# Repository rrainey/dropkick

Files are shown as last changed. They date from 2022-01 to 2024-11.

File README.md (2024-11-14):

# Dropkick
**An experimental logger for skydivers**

These devices are designed to be carried in a skydiver's breast pocket. The device loggs GPS position, barometric altitude, body rotation rates, and acceleration forces.
Data is logged to a SD card for analysis on the ground.

There are two board variants active in this project: V4 SAM, is the board I use for skydiving. V5-CAM is a design repurposed for real-time
use on a telescope pointing experiments. See [CHANGELOG.md](CHANGELOG.md) for a more detailed history.

## Sponsorship
I'd like to thank [PCBWay](https://www.pcbway.com/) for their generous sponsorship. PCBWay supplied prototype PCBs and solder stencils for the CAM variant of this project. My experience with PCBWay predates their sponsorship here. PCBWay has been a great choice for my projects. They deliver good PCBs and accurate stencils quickly.
 
 ## Description

This is a stand-alone, battery-powered data logger designed to be
carried by a skydiver during their jump.  It includes a GNSS (GPS) receiver, 6-DOF IMU, and altitude sensors. Data from all sensors is logged onto a Micro-SD card. The logged data can be reviewed post-jump by to-be-designed software.

One objective of this project is to research compact GNSS receiver performance in the dynamic environment that a skydiver routinely experiences. As such, there are currently two different u-blox receiver modules that I'm testing. There is a distinct PCB for each board variant.

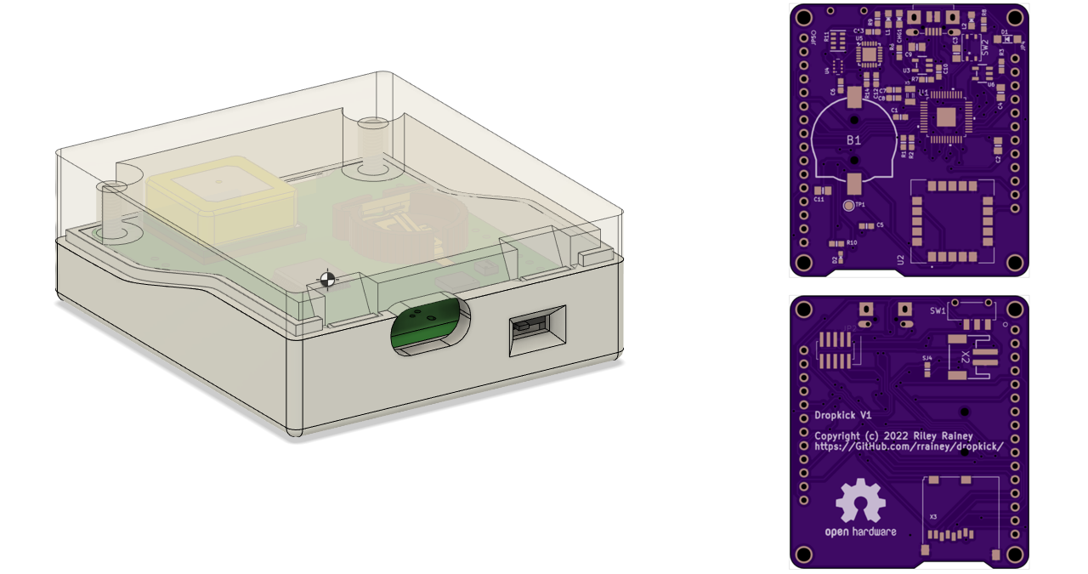
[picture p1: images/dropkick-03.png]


## Directory Structure
* **pcb-sam** - KiCad 6 PCB project files for the [u-blox SAM-M10Q](https://content.u-blox.com/sites/default/files/SAM-M8Q_DataSheet_%28UBX-16012619%29.pdf) variant (this is the preferred variant for skydiving)
* **pcb-cam** - KiCad 7 PCB project files for the [u-blox CAM-M8](https://content.u-blox.com/sites/default/files/CAM-M8-FW3_DataSheet_%28UBX-15031574%29.pdf) variant
* **enclosure** - Fusion 360 enclosure; designed to be 3D-printed
* **firmware** - Arduino-based firmware for the microcontroller
* **images** - supporting images and videos
* **analysis** - GNU Octave-based log file analysis software

Gerber production files generated by KiCad are included in the PCB directories.

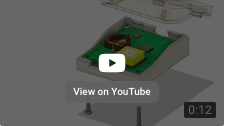
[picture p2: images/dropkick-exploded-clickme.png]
Exploding view (https://youtu.be/SXqk_i92HAI)


Exploded enclosure view (click to view)

## Specifications

Enclosure Dimensions: 58mm x 51mm x 20mm

Power: rechargeable 500mAh Li-Polymer battery

Unit Weight: 55 grams

Storage: removable microSD card

Log file format: [one log file for each jump](LOG-FORMAT.md); raw log format is an extension of NMEA0183.

USB micro-B connector (for recharging and programming)

Bootloader programmed via a 10-pin J-Link compatible connector; routine Arduino programming via the USB connector.

** Compiling Firmware
The Arduino board type should be set to "Adafruit Trinket M0" with Tiny USB enabled.

These libraries are required:
- Adafruit_BMP3XX
- ICM42688
- SparkFun u-blox GNSS Arduino_Library
- MicroNMEA  (2.0.6)
- SD (install the custom fork that I maintain on github)

## PCB Notes
My prototype circuit boards were fabricated by both OSHPark and PCBgogo. Both are excellent manufacturers for hobbyists.

### Bootloader

I flash all variants with the [Adafruit Trinket M0 UF2 bootloader](https://github.com/adafruit/uf2-samdx1/releases/download/v3.15.0/bootloader-trinket_m0-v3.15.0.bin) bin image. The current version is 3.15. Programming is performed via a Segger J-Link USB adapter using Microchip Studio (formerly Atmel Studio). Use Device = "ATSAMD21G18A". Program from the bootload .bin image file and then set the USER_WORD_0.NVMCTRL_BOOTPROT fuse to 8192 bytes.

## Solder Reflow

The solder reflow process has turned out to be a tricky step in constructing the PCBs, particularly with the SAM-M8Q IC.  Basically it requires extra heat soak in
  order to properly flow the solder.  Some u-blox instructions are repeated below, but I'll ultimately add some notes about what worked best for me.

The [u-blox Hardware Integration Manual](https://www.u-blox.com/en/docs/UBX-16018358) provides some detailed requirements for soldering the GNSS module to a PCB:

> ### Soldering paste

>Use of "no clean" soldering paste is highly recommended, as it does not require cleaning after the soldering process has taken place. The paste in the example below meets these criteria.

> * Soldering paste: OM338 SAC405 / Nr.143714 (Cookson Electronics)

> * Alloy specification: Sn 95.5/ Ag 4/ Cu 0.5 (95.5% tin/ 4% silver/ 0.5% copper)

> * Melting temperature: 217 °C

> * Stencil thickness: 120 um

> The final choice of the soldering paste depends on the approved manufacturing procedures. The paste-mask geometry for applying soldering paste should meet the recommendations. 

> ### Reflow soldering

> A convection-type soldering oven is highly recommended over the infrared-type radiation oven. Convection-heated ovens allow precise control of the temperature, and all parts will heat up evenly, regardless of material properties, thickness of components and surface color. As a reference, see the "IPC-7530 Guidelines for temperature profiling for mass soldering (reflow and wave) processes”, published in 2001.

> ### Preheat phase

>During the initial heating of component leads and balls, residual humidity will be dried out. Note that this preheat phase will not replace prior baking procedures.

> * Temperature rise rate: max. 3 °C/s. If the temperature rise is too rapid in the preheat phase it may cause excessive slumping.

> * Time: 60 - 120 s. If the preheat is insufficient, rather large solder balls tend to generate. Conversely, if performed excessively, fine balls and large balls will be generated in clusters.

> * End temperature: 150 - 200 °C. If the temperature is too low, non-melting tends to be caused in areas containing large heat capacity. 

> ### Heating and Reflow Phase

> The temperature rises above the liquidus temperature of 217 °C. Avoid a sudden rise in temperature as the slump of the paste could become worse.

> * Limit time above 217 °C liquidus temperature: 40 - 60s

> * Peak reflow temperature: 245 °C

SAC405 solder paste is relatively expensive. I have been unable to locate SAC405 in hobbyist-friendly quantities, so I opted to use SAC305 for these prototypes. The melting qualities are quite similar, and it retains the essential "no clean" properties required by U-blox -- at the cost of [potentially having slightly less sound solder connections](https://citeseerx.ist.psu.edu/viewdoc/download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,comparable%20to%20that%20of%20SAC405.).

I own a very basic infrared-type reflow oven, a Puhui T962. Even though infrared ovens are not recommended by U-blox, I decided to use it and pay careful attention to the programming of heating profile. First, I did a series to timing experiments with the standard profiles comparing them against the u-blox requirements. It turned out that my oven does not have a standard heating profile that would comply with these requirements. In particular, the closest standard profile held the oven temperature above 217 °C for roughly 90 seconds. That's far longer than the 40 to 60 seconds stated in the requirements. I had to develop a custom profile to match.

I programmed this profile into the reflow oven:
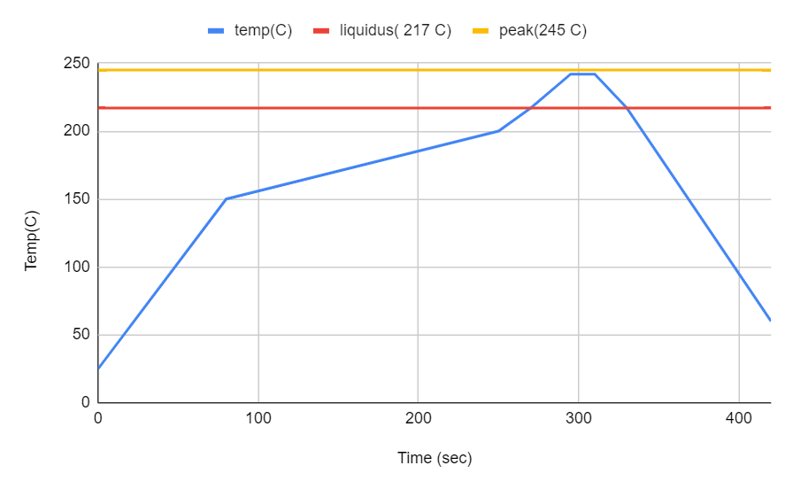
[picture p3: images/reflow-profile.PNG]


## Enclosure Notes
The enclosure is designed to be 3D printed. Tolerances between the upper enclosure, lower enclosure, and the PCB
 are quite tight - printing precision will be important. Since 3D printing technologies will vary in their precision, 
 you may need to scale or otherwise modify the objects to adequately match the final measurements in the original design.

For example, I printed the prototype enclosure on a MakerBot Replicator 2 (PLA) printer.  Using the default print settings
 I know that an object will shrink typically by about 1% post-printing.  I set the scale to 101% to compensate for that 
 in the MakerBot Desktop tooling and the end result works well.

## Credits

This PCB design is based on several Adafruit Feather and Stemma QT sensor boards.  Adafruit maintains a family of
 excellent microcontroller and sensor evaluation boards and companion software.  Support them. They deserve it.

The enclosure for this project was designed using the personal edition of Fusion 360. Autodesk supports the Maker community through access to this epic design tool.  Try it out.

## Disclaimer
THE SOFTWARE IS PROVIDED "AS IS", WITHOUT WARRANTY OF ANY KIND, EXPRESS OR IMPLIED, INCLUDING BUT NOT LIMITED TO THE WARRANTIES OF MERCHANTABILITY,
FITNESS FOR A PARTICULAR PURPOSE AND NONINFRINGEMENT. IN NO EVENT SHALL THE
AUTHORS OR COPYRIGHT HOLDERS BE LIABLE FOR ANY CLAIM, DAMAGES OR OTHER
LIABILITY, WHETHER IN AN ACTION OF CONTRACT, TORT OR OTHERWISE, ARISING FROM,
OUT OF OR IN CONNECTION WITH THE SOFTWARE OR THE USE OR OTHER DEALINGS IN THE
SOFTWARE.

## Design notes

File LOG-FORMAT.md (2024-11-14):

# Log File Format

A Dropkick log is a CSV text file. It is composed of [NMEA 0183](https://en.wikipedia.org/wiki/NMEA_0183) standard GPS records, or "sentences" using NMEA terminology,
 interspersed with the application-specific sentences described below.

 While the dropkick box is turned on, a new log file will be created when the device detects that aircraft carrying the skydiver has taken off.  Logging continues 
 until a short time after the jumper reaches the ground.

 ## Time bases

 Some NMEA sentences include a UTC timestamp computed by the GNSS receiver. A native clock in an Arduino application is the
 millis() system call.  It is a unsigned 32-bit value reflecting the number of milliseconds
 elapsed since boot time.  Both time values
 will appear in a log file.  These two timelines are designed to be correlated using information in a $PTH sentence, described below.

## NMEA Checksums

As of version 55/155, all sentences end with a three character NMEA checksum sequence ("*HH", where HH is the hex representation of the checksum byte).  These  are omitted from the examples shown below for clarity.

## $PVER Record

A single instance of this record appears as the first sentence of each log.  It documents
 the software version used to create the file. The app version is an integer version number; the "hundreds" digit is used to
 designate whether the file originated from a Dropkick(0) or the newer Tempo board(1). This is an imperfect scheme.  It will make for future issues
 with versioning semantics. I'll have to fix that with an updated version of this sentence some time later.

### Comma-separated Fields

 | Description   |                                        |
 |---------------|----------------------------------------|
| $PVER         | Record identifier                      |
| id string | ID of this app version   |
| version number       | an integer version number of the application; a '1' in the decimal hundreds place indicatess it was created by Tempo, not Dropkick        |

### Example 

`$PVER,"Dropkick, version 0.52",52`

## $PIMU Record

### For Dropkick boards

PIMU record logs sensor information from the [MPU6050 IMU IC](https://invensense.tdk.com/wp-content/uploads/2015/02/MPU-6000-Datasheet1.pdf).  The MPU6050 is mounted on the
Dropkick PCB such that the positive X-Axis projects out the SD card slot, the positive Y-Axis projects out the face opposite the USB port, and the positive Z-Axis projects out the "top" of the enclosure.  Since the device might be carried by a skydiver in almost any orientation, it would be up to analysis software to discern the body orientation inferred by actual readings.

### For Tempo boards

The ICM42688-V IMU is installed on Tempo Boards. Values are reported in Case Axes (body axes), shown below.

### Comma-separated Fields

| Description | |
|---|---|
| $PIMU | Record identifier |
| millis() timestamp | Time of sample in milliseconds |
| X-accel | expressed in meters per second squared |
| Y-accel | expressed in meters per second squared |
| Z-accel | expressed in meters per second  squared |
| X-rate | raw X rotation rate; expressed in radians per second |
| Y-rate | raw Y rotation rate; expressed in radians per second |
| Z-rate | raw Z rotation rate; expressed in radians per second |

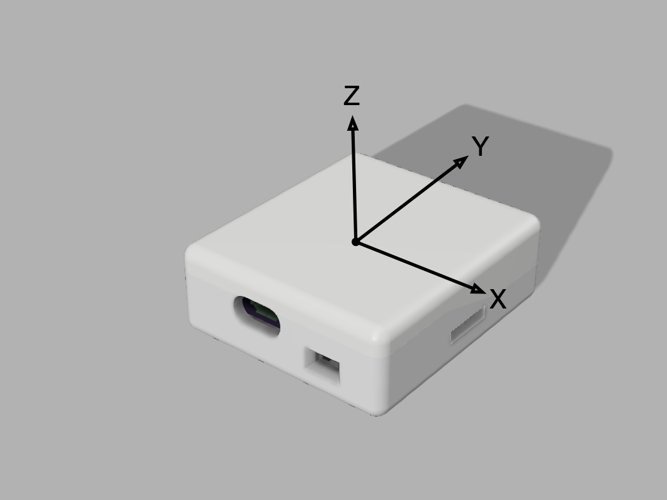
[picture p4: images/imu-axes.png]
Dropkick axes

Dropkick board Body Axes

Tempo Frames
Template board Axes, including the Case (or Body) Axis definitions

## $PIM2 Record (Tempo boards only)

This is the real-time orientation of the jumper expressed as a [Quaternion](https://en.wikipedia.org/wiki/Quaternions_and_spatial_rotation).

The application maintains this orientation quaternion using a 200Hz sample
stream from the IMU. A startup value of [1,0,0,0] is used,
and orientation quaternion is updated to reflect all changes in the body axes from
that original orientation.

This raw orientation quaternion must be transformed into some world frame of reference - North-East-Down, for example - 
in order for it to be useful in analysis of a jump.  I have a few approaches to this in mind, but it remains
as future work in this project.

### Comma-separated Fields

| Description | |
|---|---|
| $PIM2 | Record identifier |
| millis() timestamp | Time of sample in milliseconds |
| W | quaternion w component, non-dimensional |
| X | quaternion x component, non-dimensional |
| Y | quaternion y component, non-dimensional |
| Z | quaternion z component, non-dimensional |

### $PIM2 Example

`$PIM2,13925127,1.0000,0.0000,0.0000,0.0000`

## $PENV Record

This record logs pressure information captured from the 
[DPS310 sensor IC](https://www.infineon.com/dgdl/Infineon-DPS310-DataSheet-v01_02-EN.pdf?fileId=5546d462576f34750157750826c42242) and a resistor ladder used to monitor the VBATT battery line voltage level.

### Comma-separated Fields
| Description | |
|---|---|
| $PENV | Record identifier |
| millis() timestamp | Time of sample in milliseconds |
| static air  pressure | expressed in hPa |
| estimated altitude | based on static air pressure reading for a standard day; expressed in feet |
| VBATT voltage | battery voltage level (3.5V - 3.8V typ.); sampled once every 30 seconds; 
battery voltage isn't reported  on Tempo boards: the value will be set to -1    |

### $PENV Example

`$PENV,13925040,984.62,791.18,3.79`

## $PTH Record

 A PTH record is used to correlate Arduino millis() timestamps with the GNSS computed time of day
  clock information that appears in standard NMEA sentences.  A PTH record will appear immediately 
  following each NMEA GGA or GGL record.  The timestamp present in the record reflects the millis() time at the arrival
  of the first character of the NMEA record.

### $PTH Example

`$PTH,13925296`

## $PSFC Record

This records the estimated surface altitude of the landing area. This value is currently computed directly from the static air pressure assuming a [standard air pressure
lapse rate](https://en.wikipedia.org/wiki/Atmospheric_pressure).

This value can be subtraced from the altitude reports in $PENV sentences to obtain an estimated height above ground level (AGL)

### Comma-separated Fields

| Description | |
|---|---|
| $PSFC | Record identifier |
| estimated surface altitude | Expressed in feet, MSL. Technically speaking, this value reflects the pressure sampled at the device. |

### $PSFC Example

`$PSFC,880`

# $PST Record

This record records application state changes. This internal state machine is used to
identify when to start and stop logging of each jump. 

The application defines WAIT, FLIGHT, JUMPING, and LANDED1 states.  This information might be useful to
isolate specific segments of the jump during post-jump analysis.

### Comma-separated Fields

| Description | |
|---|---|
| $PSFC | Record identifier |
| millis() timestamp | Time of state change in milliseconds |
| New State | WAIT, FLIGHT, JUMPING, or LANDED1  |

### $PST Example

`$PST,1000,FLIGHT`

## Sentence Reporting Rates

Sensor records are written to the file at these rates:

| Sentence Type |  Reporting Rate |
|:---:|:---|
|  PVER | appears as the first line of a log file |
|  PSFC | follows the PVER sentence |
|  GNSS position report | 2 Hz |
|  PIMU | 40 Hz |
|  PIM2 | follows each $PIMU sentence|
|  PENV | 4 Hz |
|  PTH | follows each GGA and VTG record|
|  PST | at each internal state change in the logger |

Valid for version 55/155 and later

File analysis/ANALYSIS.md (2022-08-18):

## General

The main module of this GNU Octave code is Modeler.m.

```bash
$ octave
octave:1>  [t_plot, a_norm_plot, a_filt_plot, ssim] = Modeler.analyze('LOG00014.TXT');
```

The objective is to explore the feasibility to use IMU to accurately estimate the
pose and location of the jumper in freefall and while under canopy.

Pose estimation will require accuracy in both initialization and pose updates.  During initialization, GNSS location fixes and track information can be combined with the apparent gravity vector to keep orientation, position, and velocity information
up to date. Once we detect that the jump has started, we can then transition to using the IMU's roll rate and acceleration sensors to
calculate changes in state.

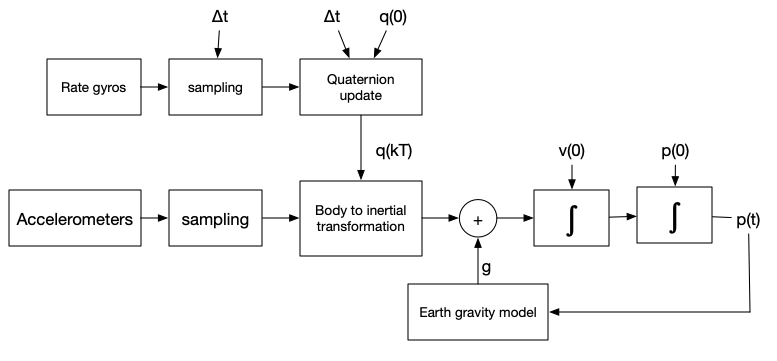
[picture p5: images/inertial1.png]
Basic inertial computations based on IMU sensors


$$
\begin{bmatrix}
\dot{q_0} \\
\dot{q_1} \\
\dot{q_2} \\
\dot{q_3}
\end{bmatrix} = - \frac{1}{2} \begin{bmatrix*}[r] 
 0  &  P  &  Q  &  R \\
-P  &  0  & -R  & Q \\
-Q  &  R  & 0   & -P \\
-R  & -Q  &  P  &  0 \\
\end{bmatrix*}
\begin{bmatrix}
q_0 \\
q_1 \\
q_2 \\
q_3
\end{bmatrix}
$$

From ANSI/AIAA R-004-1992 "Atmospheric and Space Flight Vehicle Coordinate Systems"; Euler body angles can be recovered from an orientation Quaternion in this way:

$$
\begin{split}
\phi & =\arctan[ \frac{ 2( q_2 q_3 + q_0 q_1 ) }{ ( q_0^2 + q_3^2 - q_1^2 - q_2^2 ) } ] \\
\\
\theta & = \arcsin[-2 ( q_1 q_3 - q_0 q_2 )] \\
\\
\psi & =  \arctan[ \frac{2( q_1 q_2 + q_0 q_3 ) }{( q_0^2 + q_1^2 - q_2^2 - q_3^2 ) } ] \\
\\
\end{split}
$$

For orientation quaternion initialization, (estimated) body angles may be used:

$$
\begin{split} 
\\
q_0 & = \cos(\frac{\psi}{2}) \cos(\frac{\theta}{2})  \cos(\frac{\phi}{2 }) + 
      \sin(\frac{\psi}{2}) \sin(\frac{\theta}{2})  \sin(\frac{\phi}{2 }) \\
\\
q_1 & = \cos(\frac{\psi}{2}) \cos(\frac{\theta}{2})  \sin(\frac{\phi}{2 }) -
      \sin(\frac{\psi}{2}) \sin(\frac{\theta}{2})  \cos(\frac{\phi}{2 }) \\
\\
q_2 & = \cos(\frac{\psi}{2}) \sin(\frac{\theta}{2})  \cos(\frac{\phi}{2 }) +
      \sin(\frac{\psi}{2}) \cos(\frac{\theta}{2})  \sin(\frac{\phi}{2 }) \\
\\
q_3 & = - \cos(\frac{\psi}{2}) \sin(\frac{\theta}{2})  \sin(\frac{\phi}{2}) +
      \sin(\frac{\psi}{2}) \cos(\frac{\theta}{2})  \cos(\frac{\phi}{2}) \\
\\
\end{split}
$$

Body axes are AIAA-standard, which is X out-the-nose, Y out-the-right-wing, and Z down.

The AIAA-standard North-East-Down coordinate frame is used to express world cordinates. Origin X and Y coordinates for each log file are arbirarily chosen to be the XY location at the start of the log. If needed, the first reported GNSS position may be used to establish the NED origin (with appropriate Z correction applied to compensate for altitude)

| Variables | |
|:---:|---|
| $P, Q, R$ | Body angular velocity rates (sampled) (rad/sec) |
| $a_{B}$ | Sampled body acceleration (m/sec^2)
| $a, v, p$ | 3D Acceleration (sampled), velocity, and position in NED frame (meters) |
| $q$ | Body orientation quaterion (NED Frame) |
| $\phi, \theta, \psi$ | roll, pitch, yaw body angles (radians) |

The gravity model used during analysis is to be determined.

Adams-Bashforth third-order integration will ultimately be used to integrate NED velocity and position.

$$x_{n+1} = x_{n} + \frac{T}{12} ( 5 \dot{x}_{n+1} + 8 \dot{x}_n - \dot{x}_{n-1} ) $$

Where $T$ is the time step.

Euler integration is used for the first two time steps to prime the ABM integrator.

NOTE: In the current version of the code, Euler integration is used throughout.

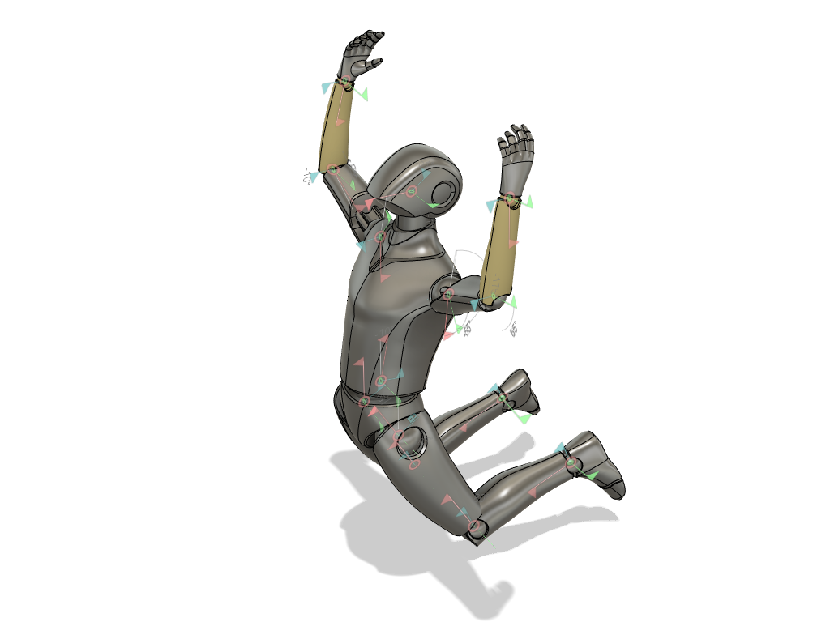
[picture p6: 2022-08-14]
images/jumper-01.png

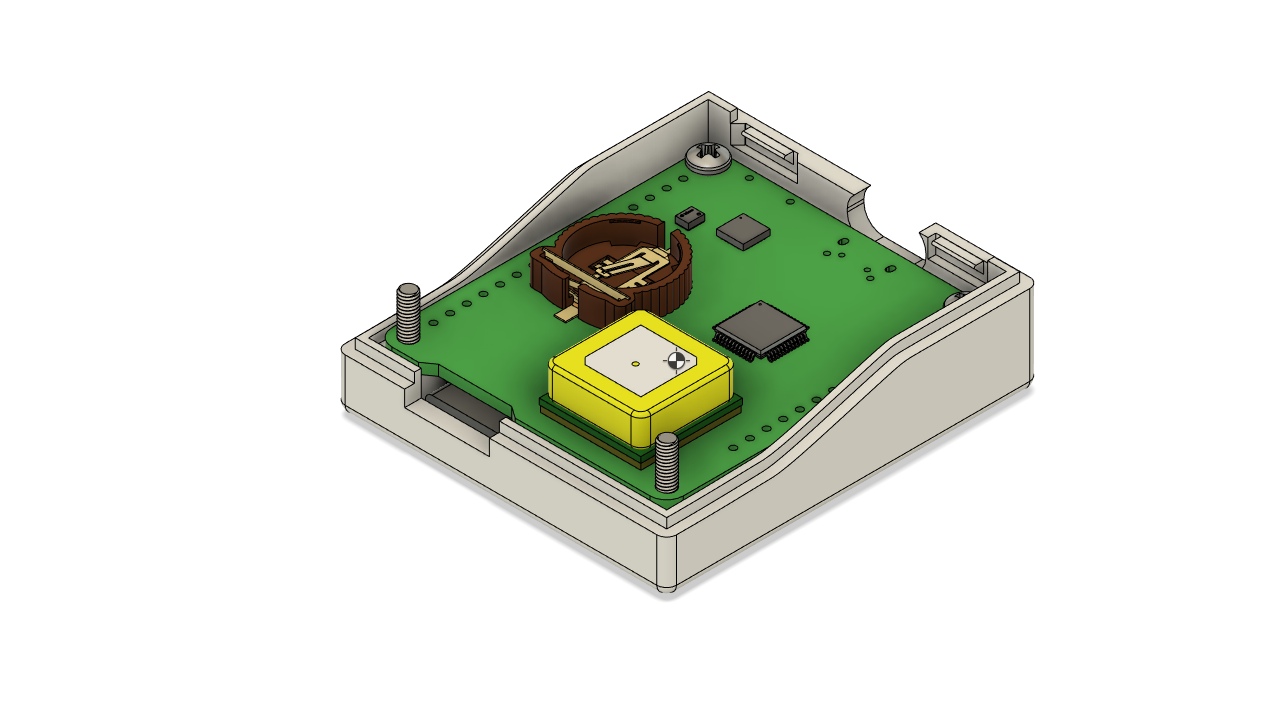
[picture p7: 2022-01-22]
images/dropkick-01.png

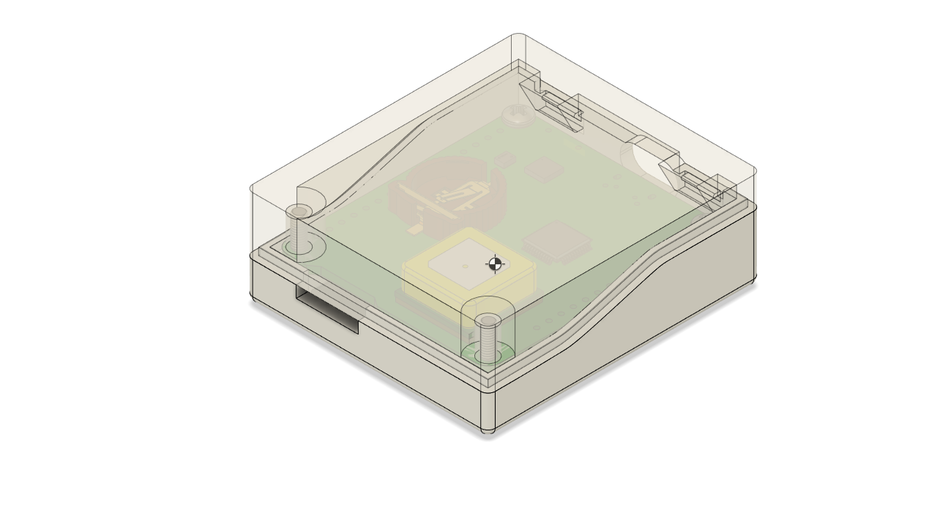
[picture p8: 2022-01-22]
images/dropkick-02.png

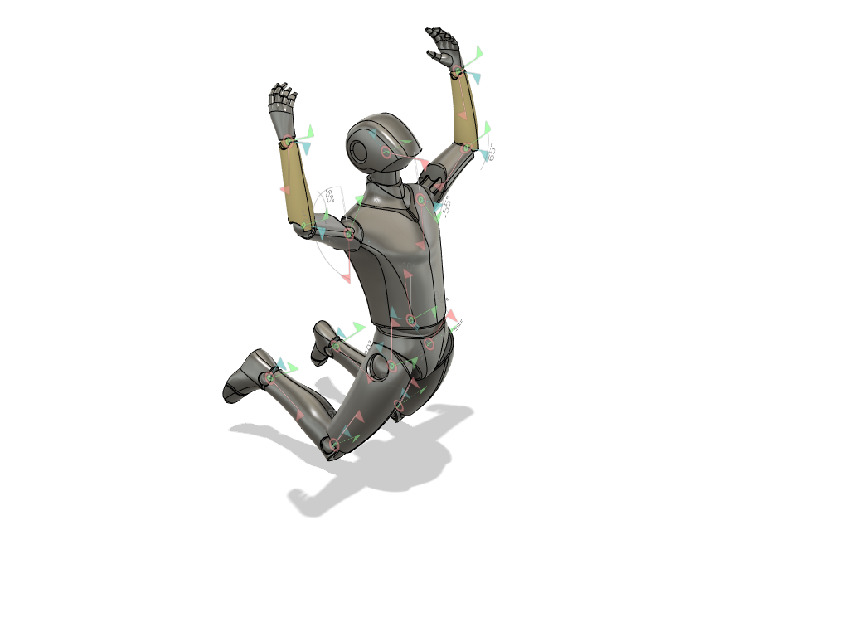
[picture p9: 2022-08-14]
images/jumper-02.png

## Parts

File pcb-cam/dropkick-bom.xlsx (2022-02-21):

Reference | Quantity | Value | Footprint
B1 | 1 | CR1220 | CR1220-2
C1 C5 C10 | 3 | 1uF | Capacitor_SMD:C_0603_1608Metric
C13 | 1 | 2.2nF | Capacitor_SMD:C_0603_1608Metric
C2 C11 | 2 | 10uF | Capacitor_SMD:C_0805_2012Metric
C3 C4 C9 | 3 | 10µF | Capacitor_SMD:C_0805_2012Metric
C6 C12 | 2 | 0.1uF | Capacitor_SMD:C_0603_1608Metric
C7 C8 | 2 | 22pF | Capacitor_SMD:C_0603_1608Metric
CHG1 | 1 | ORANGE | CHIPLED_0805_NOOUTLINE
D1 | 1 | MBR120 | SOD-123
D2 | 1 | GREEN | CHIPLED_0603_NOOUTLINE
H1 H2 H3 H4 | 4 | MountingHole | logger:MOUNTINGHOLE_2.5_PLATED
J1 | 1 | Conn_01x08 | Connector_PinHeader_2.54mm:PinHeader_1x08_P2.54mm_Vertical
JP2 | 1 | 3221-10-0300-00-TR | lib_fp:3221-10-0300-00-TR
L1 | 1 | GREEN | CHIPLED_0805_NOOUTLINE
L2 | 1 | RED | CHIPLED_0805_NOOUTLINE
R1 R2 R3 | 3 | 100K | Resistor_SMD:R_0603_1608Metric
R4 R5 | 2 | 0K | Resistor_SMD:R_0603_1608Metric
R6 R10 R11 R12 R14 | 5 | 10K | Resistor_SMD:R_0603_1608Metric
R7 R9 | 2 | 1K | Resistor_SMD:R_0603_1608Metric
R8 | 1 | 2.2K | Resistor_SMD:R_0603_1608Metric
SJ4 | 1 | SOLDERJUMPER | Resistor_SMD:R_0603_1608Metric
SW1 | 1 | 450405020524 | logger:450405020524
SW2 | 1 | KMR211NG_LFS | logger:KMR211NG LFS
TP1 | 1 | TESTPOINTROUND1.5MM | TESTPOINT_ROUND_1.5MM
U1 | 1 | ATSAMD21G18A-AUT | logger:ATSAMD21G15B-AU
U2 | 1 | CAM-M8C-0 | lib_fr:CAM-M8C-0
U3 | 1 | MCP73831T-2ACI/OT | SOT23-5
U4 | 1 | DPS310XTSA1 | logger:DPS310XTSA1
U5 | 1 | MPU-6050 | QFN24_4MM_SMSC
U6 | 1 | SPX3819-3.3 | SOT23-5
X1 | 1 | microUSB | 4UCONN_20329_V2
X2 | 1 | JSTPH | JSTPH2
X3 | 1 | microsd | MICROSD
X4 | 1 | ANTENNA_U.FL | lib_fr:U.FL
X5 | 1 | 32768Hz | XTAL3215

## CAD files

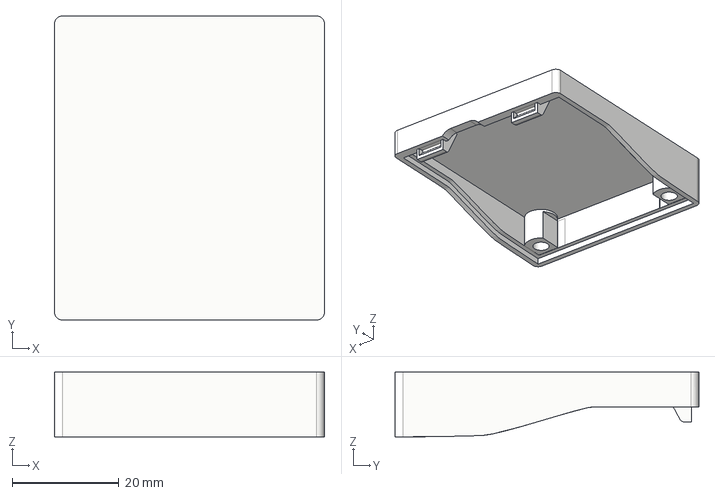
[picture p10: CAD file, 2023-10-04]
enclosure/Upper.step
50.5 x 56.9 x 12.1 mm

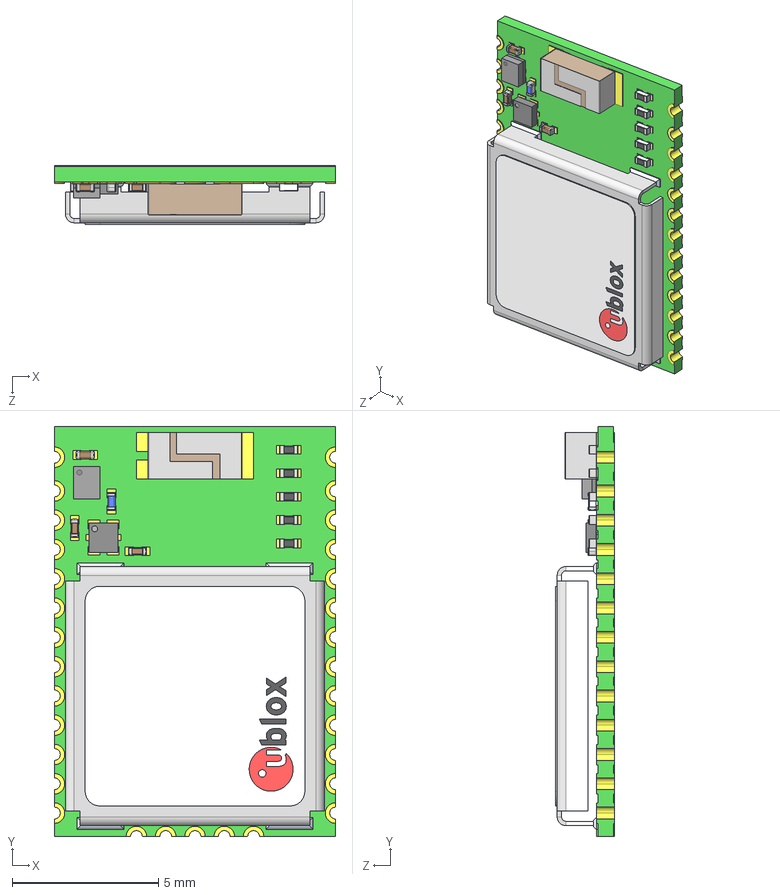
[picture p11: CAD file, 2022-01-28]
pcb-cam/models/CAM.STEP
9.60 x 14.0 x 2.00 mm
SAW_FILTER
C0201 x 3
L0201
NJG1143UA2
SHIELDING_COVER_FOR_CAM_Default
R0201 x 5
CAM_PCB
GPS_CHIP_ANT
u-blox_MAX_label_Default

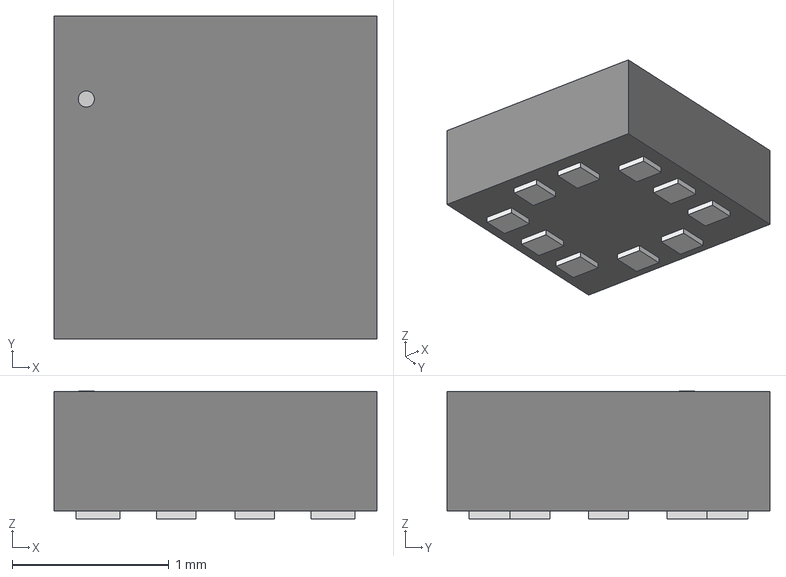
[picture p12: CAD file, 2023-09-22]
pcb-sam/models/LGA10_BMP390_BOS.step
2.06 x 2.06 x 0.815 mm

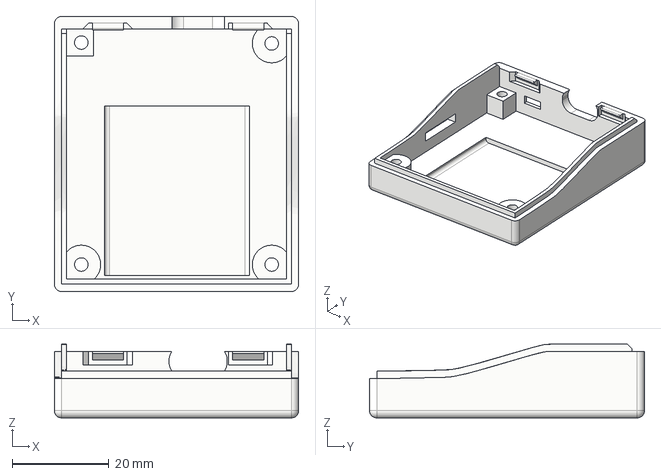
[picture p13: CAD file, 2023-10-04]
enclosure/Lower.step
50.5 x 56.9 x 15.3 mm

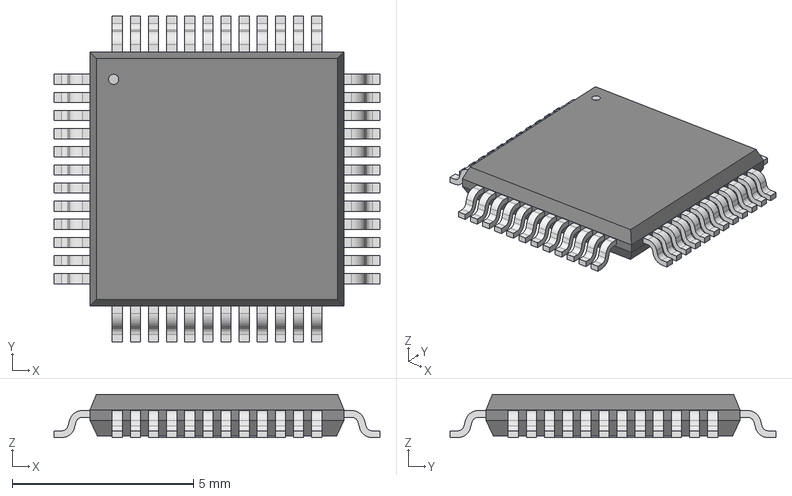
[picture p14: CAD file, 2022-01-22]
pcb-cam/models/TQFP48_7x7MC_MCH.step
8.99 x 8.99 x 1.20 mm

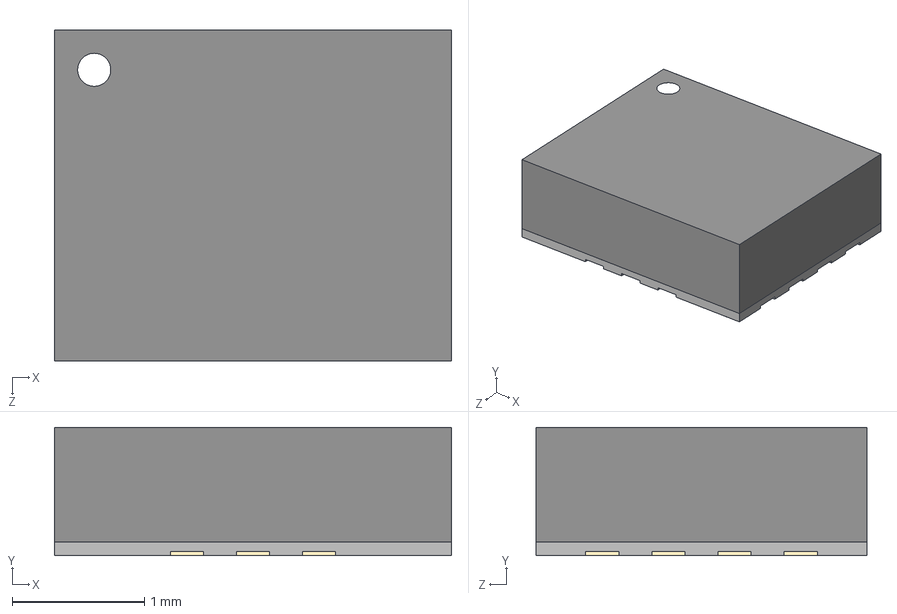
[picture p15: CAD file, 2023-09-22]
pcb-sam/models/ICM-42688-P.step
3.00 x 0.97 x 2.50 mm

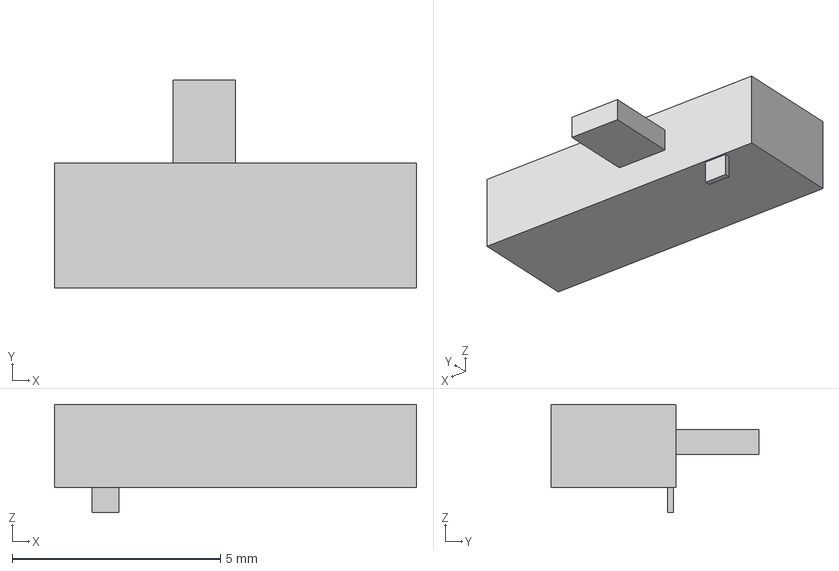
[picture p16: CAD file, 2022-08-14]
enclosure/switch.step
8.70 x 5.00 x 2.60 mm

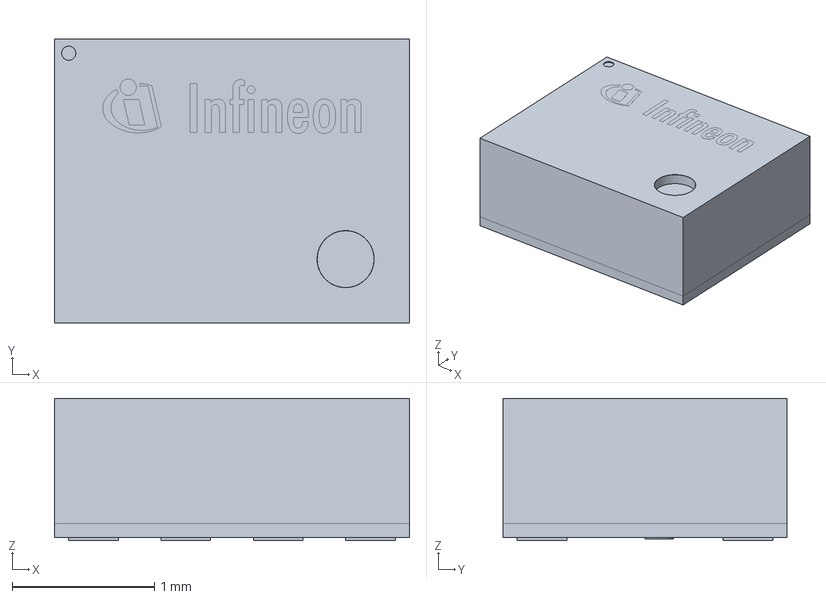
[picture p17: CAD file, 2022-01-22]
pcb-cam/models/DPS310XTSA1.stp
2.50 x 2.00 x 1.00 mm
CADSOFTTOOLS 2.1
CADSOFTTOOLS 2.2
CADSOFTTOOLS 2.3
CADSOFTTOOLS 2.4
CADSOFTTOOLS 2.5
CADSOFTTOOLS 2.6
CADSOFTTOOLS 2.7
CADSOFTTOOLS 2.8
CADSOFTTOOLS 2.9
CADSOFTTOOLS 2.10
CADSOFTTOOLS 2.11
CADSOFTTOOLS 2.12
CADSOFTTOOLS 2.13
CADSOFTTOOLS 2.14
CADSOFTTOOLS 2.15
CADSOFTTOOLS 2.16
CADSOFTTOOLS 2.17
CADSOFTTOOLS 2.18
CADSOFTTOOLS 2.19
CADSOFTTOOLS 2.20
CADSOFTTOOLS 2.21
CADSOFTTOOLS 2.22
CADSOFTTOOLS 2.23
CADSOFTTOOLS 2.24
CADSOFTTOOLS 2.25
CADSOFTTOOLS 2.26
CADSOFTTOOLS 2.27
CADSOFTTOOLS 2.28
CADSOFTTOOLS 2.29
CADSOFTTOOLS 2.30
CADSOFTTOOLS 2.31
CADSOFTTOOLS 2.32
CADSOFTTOOLS 2.33
CADSOFTTOOLS 2.34
CADSOFTTOOLS 2.35
CADSOFTTOOLS 2.36
CADSOFTTOOLS 2.37
CADSOFTTOOLS 2.38
CADSOFTTOOLS 2.39
CADSOFTTOOLS 2.40
CADSOFTTOOLS 2.41
CADSOFTTOOLS 2.42
CADSOFTTOOLS 2.43
CADSOFTTOOLS 2.44
CADSOFTTOOLS 2.45
CADSOFTTOOLS 2.46
CADSOFTTOOLS 2.47
CADSOFTTOOLS 2.48
CADSOFTTOOLS 2.49
CADSOFTTOOLS 2.50
CADSOFTTOOLS 2.51
CADSOFTTOOLS 2.52
CADSOFTTOOLS 2.53
CADSOFTTOOLS 2.54
CADSOFTTOOLS 2.55
CADSOFTTOOLS 2.56
CADSOFTTOOLS 2.57
CADSOFTTOOLS 2.58
CADSOFTTOOLS 2.59
CADSOFTTOOLS 2.60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

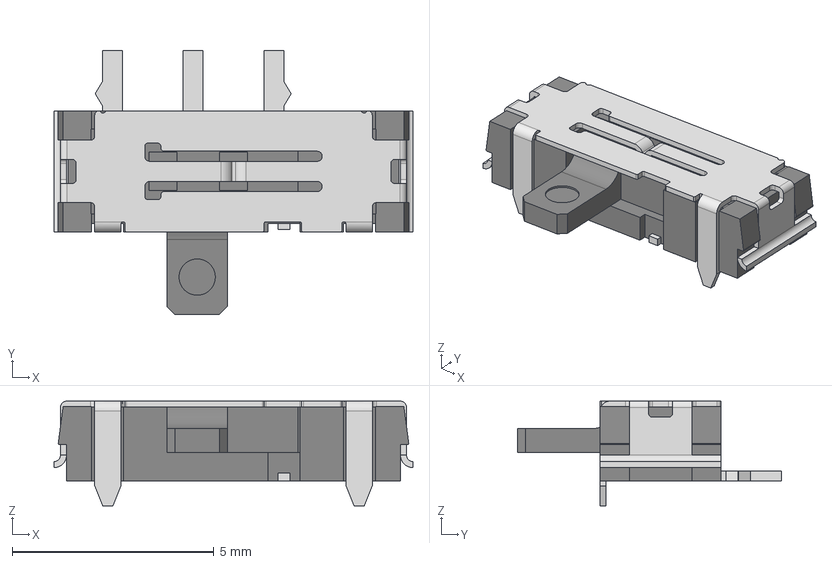
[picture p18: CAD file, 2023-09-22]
pcb-sam/models/STP_450405020524 (rev1).stp
8.90 x 6.55 x 2.60 mm
Frame
Cover
Pin 2
Pin 4
Slider 1
Pin 1
Pin 3
Slider
Pin 5

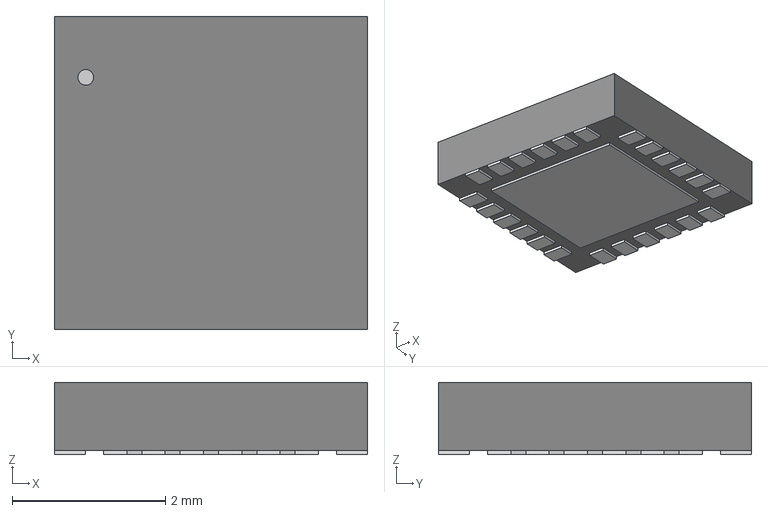
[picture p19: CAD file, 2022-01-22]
pcb-cam/models/QFN24_4X4X0P9_IVS.step
4.09 x 4.09 x 0.942 mm

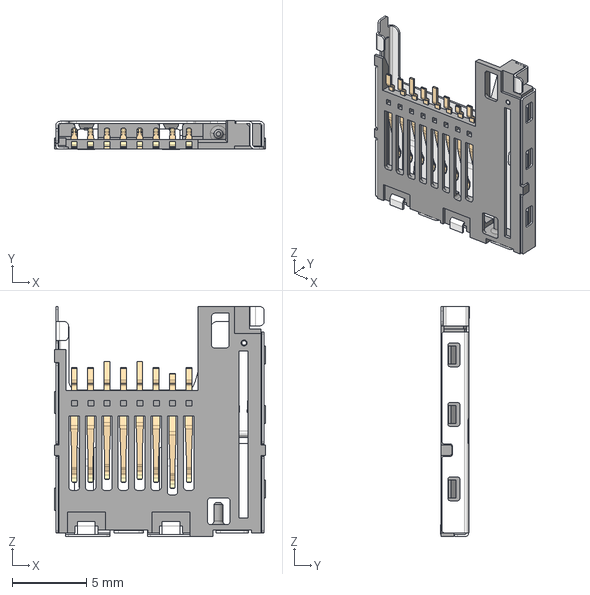
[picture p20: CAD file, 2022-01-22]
pcb-cam/models/MEM2061-01-188-00-A.stp
14.2 x 1.95 x 15.5 mm
ÇÐ³ý-ÀÉì2[2]
ÇÐ³ý-ÀÉì-±¡±Ú2

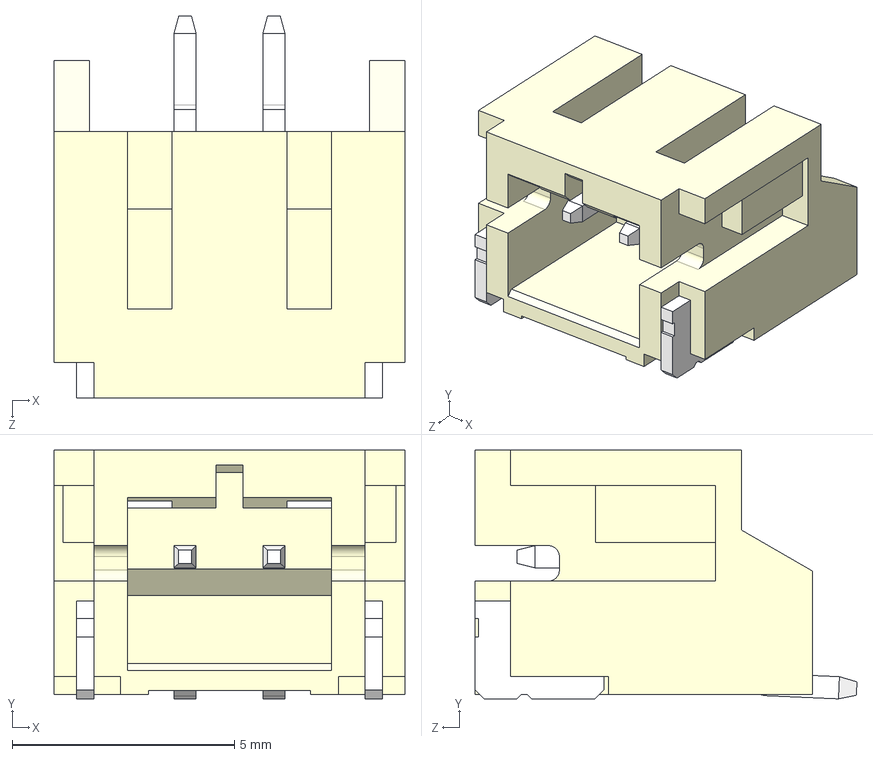
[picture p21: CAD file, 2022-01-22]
pcb-cam/models/S2B-PH-SM4-TB(LF)(SN)--3DModel-STEP-56544.STEP
7.90 x 5.60 x 8.60 mm

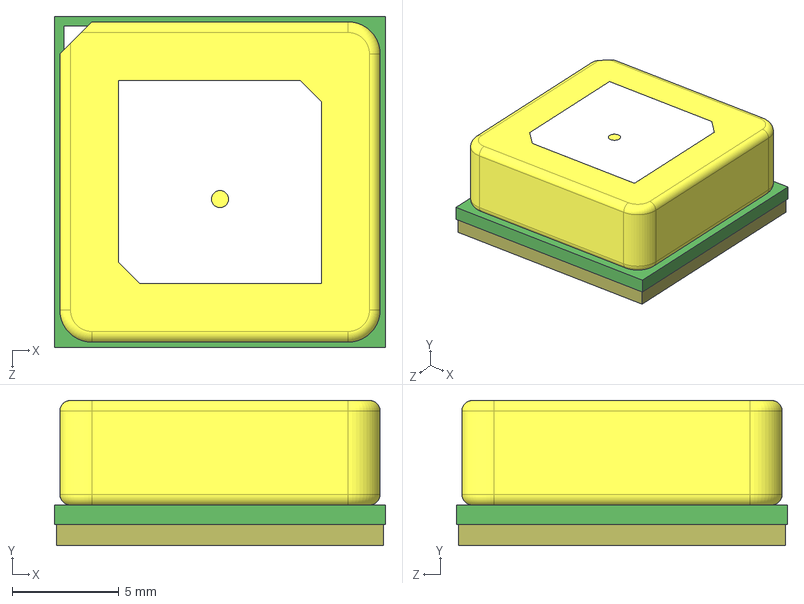
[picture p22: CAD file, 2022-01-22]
pcb-sam/models/SAM-M8Q-0-10.step
15.5 x 6.80 x 15.5 mm

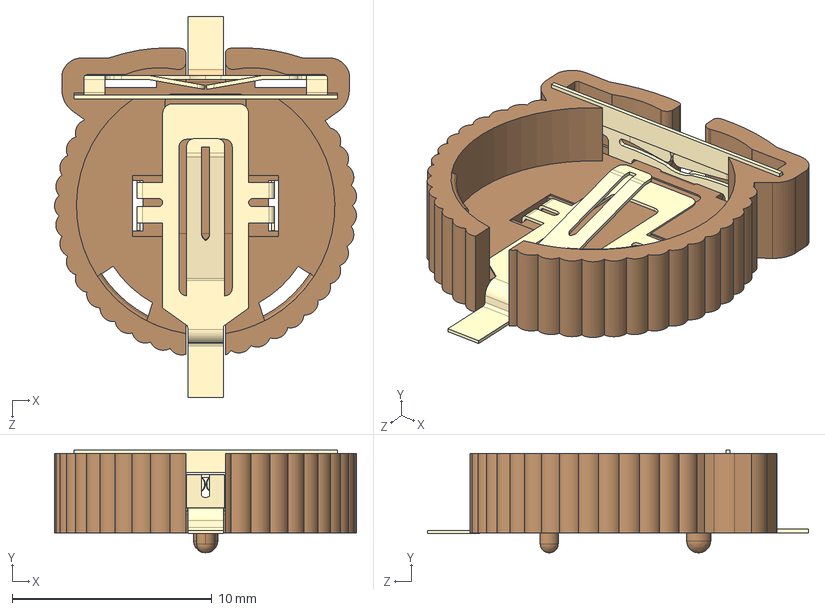
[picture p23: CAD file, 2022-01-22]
pcb-cam/models/keystone-PN1056TR.STEP
15.1 x 5.16 x 19.1 mm

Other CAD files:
enclosure/dropkick.f3z
pcb-cam/models/10103594.stp
pcb-cam/models/20021521-00010XXLFc.stp
pcb-sam/models/10103594.stp
pcb-sam/models/20021521-00010XXLFc.stp

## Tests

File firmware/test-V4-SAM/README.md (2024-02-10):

# TEST-V4-SAM

## A, Arduino sketch designed to strees test the Dropkick SAM V4 board.
This sketch is designed for checkout and stress testing of the
Dropkick SAM V4 board.  This revised board design switched to newer GNSS, IMU, and barometric pressure sensors, so this sketh will not work with earlier variants.

Arduino board configuration settings:

```json
{
    "configuration": "opt=fastest,usbstack=arduino,debug=off",
    "board": "adafruit:samd:adafruit_trinket_m0",
    "sketch": "test-V4-SAM.ino",
    "port": "COM14"
}
```

Your USB port assignment will vary, of course.

## Notes and conclusions
The Dropkick board uses I2C to communicate with all sensors. The newer "peakick" board project does the same.  Both boards exhibit intermittent issues when trying to interact
with sensors at higher sampling rates, probably due to intermittent I2C bus issues.  I did spend some time tuning the I2C bus configuration of both boards, mostly by optimizing the pull-up resistor values.  After tuning, the reliability improved, but intermittent issues persist. Based on that, I have decided that the completely new Tempo board design will use an SPI rather than I2C for the ICM42688 IMU (see https://github.com/rrainey/tempo).

## Credits
This sketch use a custom ICM42688 library.  This IMU driver code is based upon code published by Kris Winer, copyrighted by Tlera Corporation.  I added extensions to add support for the ICM42688 FIFO, interrupts, and allow for better error reporting.  The original code was marked as 
"Library may be used freely and without limit with attribution".  Thank you, Kris and Tlera.  (see https://github.com/kriswiner/ICM42688)

This sketch also includes BMP3-series driver reference code from Bosch Sensortec GmbH. See [BMP3-LICENSE](./BMP3-LICENSE) and https://github.com/boschsensortec/BMP3-Sensor-API for more information.

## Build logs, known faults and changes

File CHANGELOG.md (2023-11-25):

# Dropkick CHANGELOG

## 2023-10-15 CAM V5 Assembly
- assembled and tested first v5-cam board - defective CAM receiver part

## 2023-10-01 CAM V5 Board
- Use internal antenna for the CAM-M8C GNSS Module
- revise CAM-M8C layout to get a cleaner ground plane
- add 30 ohm resistors on CAM-M8C I2C lines to reduce noise
- revise MPU-6050 PCB layout to more closely match the datasheet
- add header lines for SWD programming, switch to 2.0 mm spacing on header

## 2023-09-10 SAM V4 PCB Board
I decided to revise the SAM variant PCB to use more modern ICs:

- Change GNSS to the u-blox SAM-M10Q (the M10Q is pin compatible with the M8Q)
- Change IMU to TDK InvenSense ICM-42688
- Add hardware interrupt lines from the IMU
- Change barometric sensor to the Bosch BMP-390
- Switch to a USB-C connector

## 2022-09-03
I have resolved the buffering issue in the GNSS reporting stream and continue to work on developing analysis tools using Octave.

## 2022-08-18
I have collected the first log files from several jumps. GPS data is usable, although there are intermittent u-blox buffering errors
 interspersed in these logs. I have been exploring the feasibility of pose reconstruction from IMU log data.
 I am using GNU Octave for this investigation. The code resides in the ./analysis subdirectory.  It should be considered entirely experimental
 at this stage - don't trust the accuracy of any of that code based on where I am today.

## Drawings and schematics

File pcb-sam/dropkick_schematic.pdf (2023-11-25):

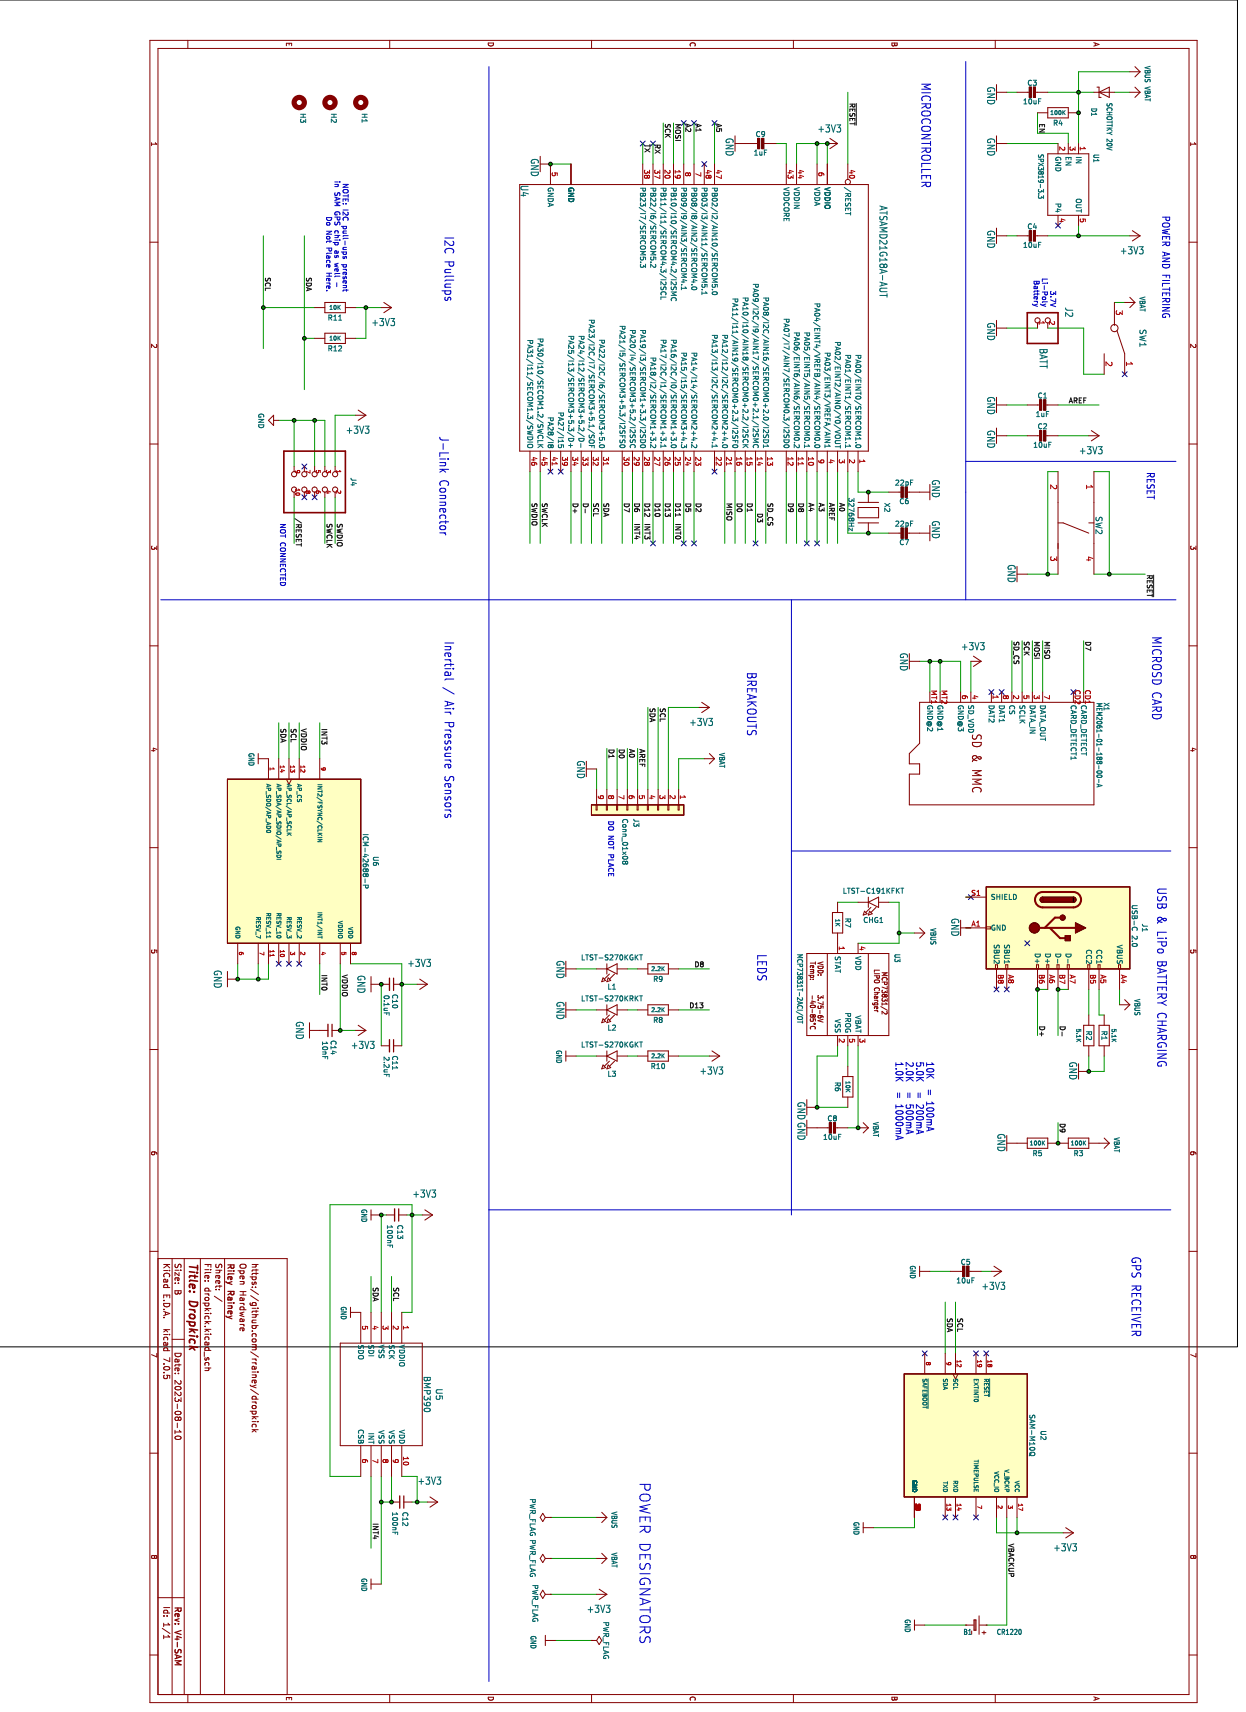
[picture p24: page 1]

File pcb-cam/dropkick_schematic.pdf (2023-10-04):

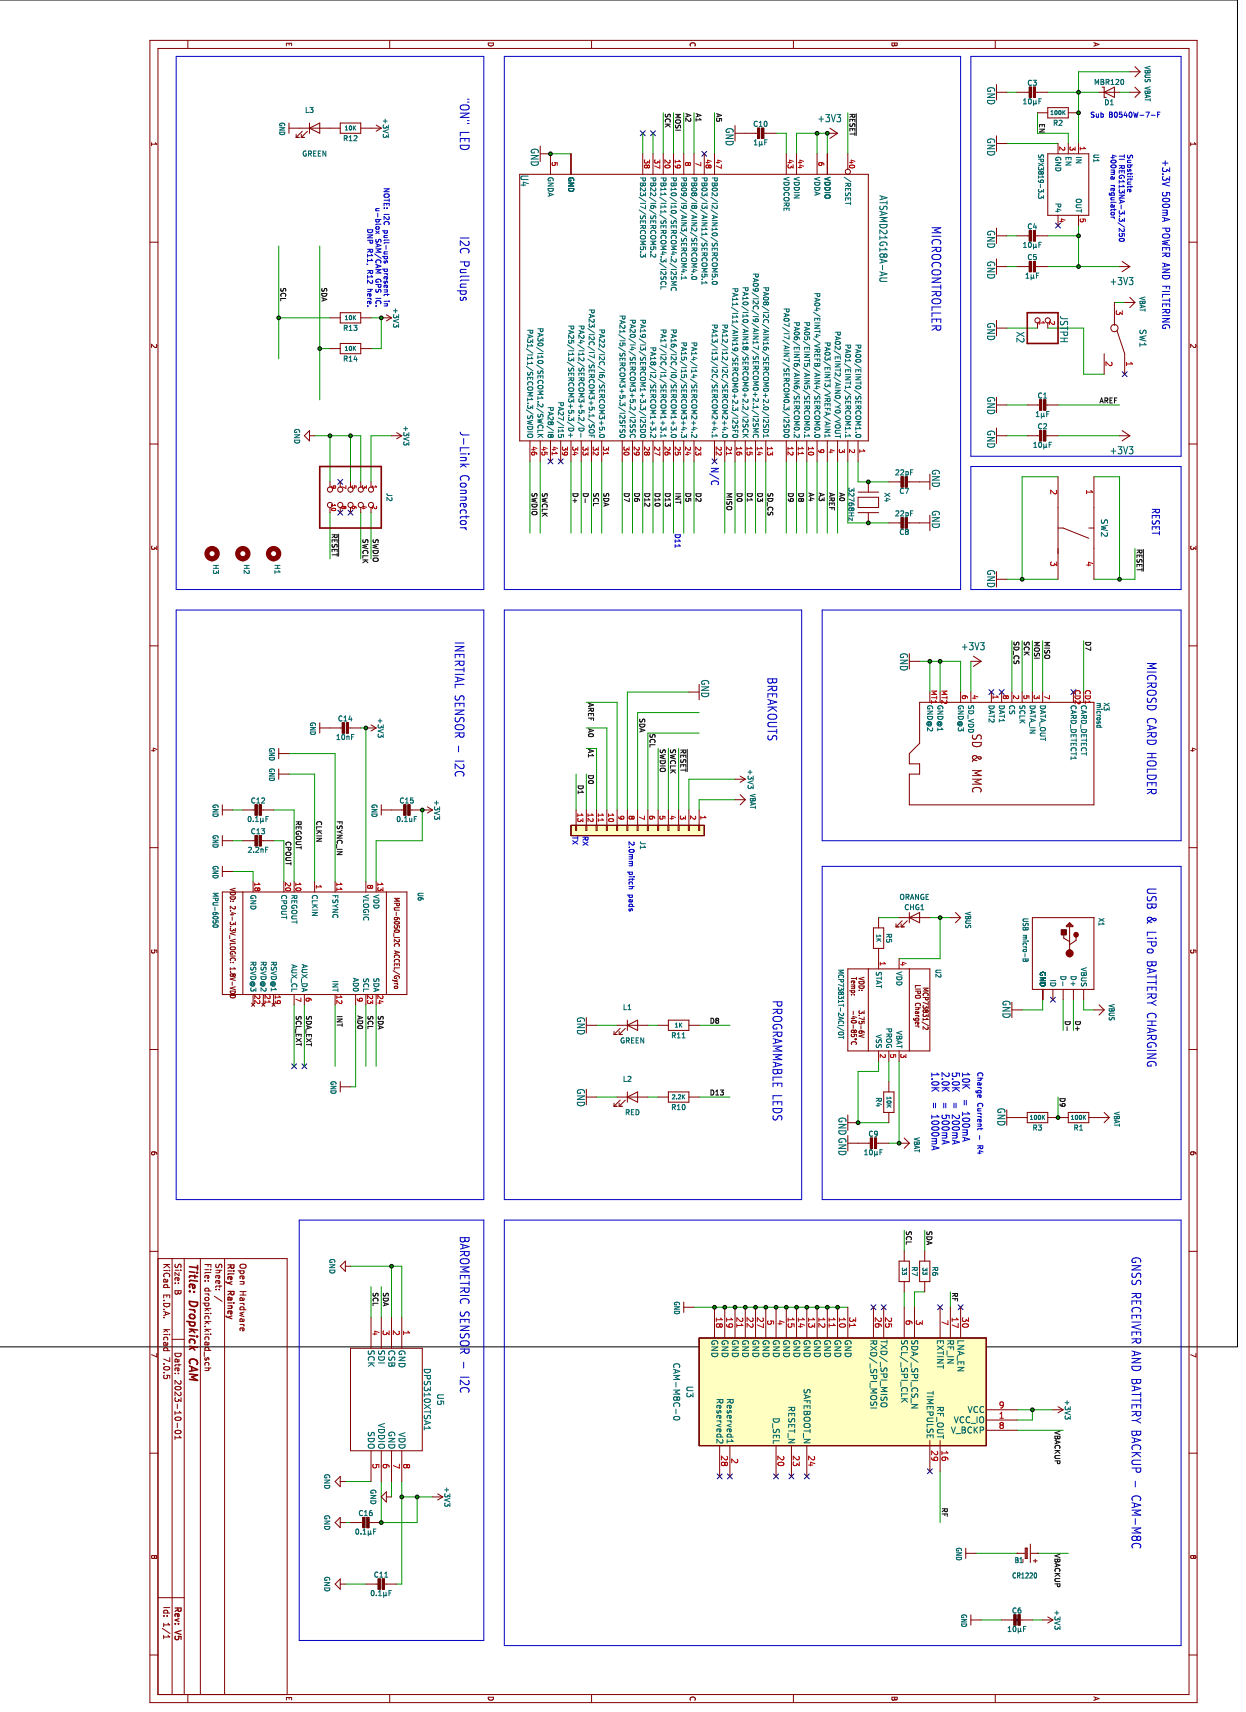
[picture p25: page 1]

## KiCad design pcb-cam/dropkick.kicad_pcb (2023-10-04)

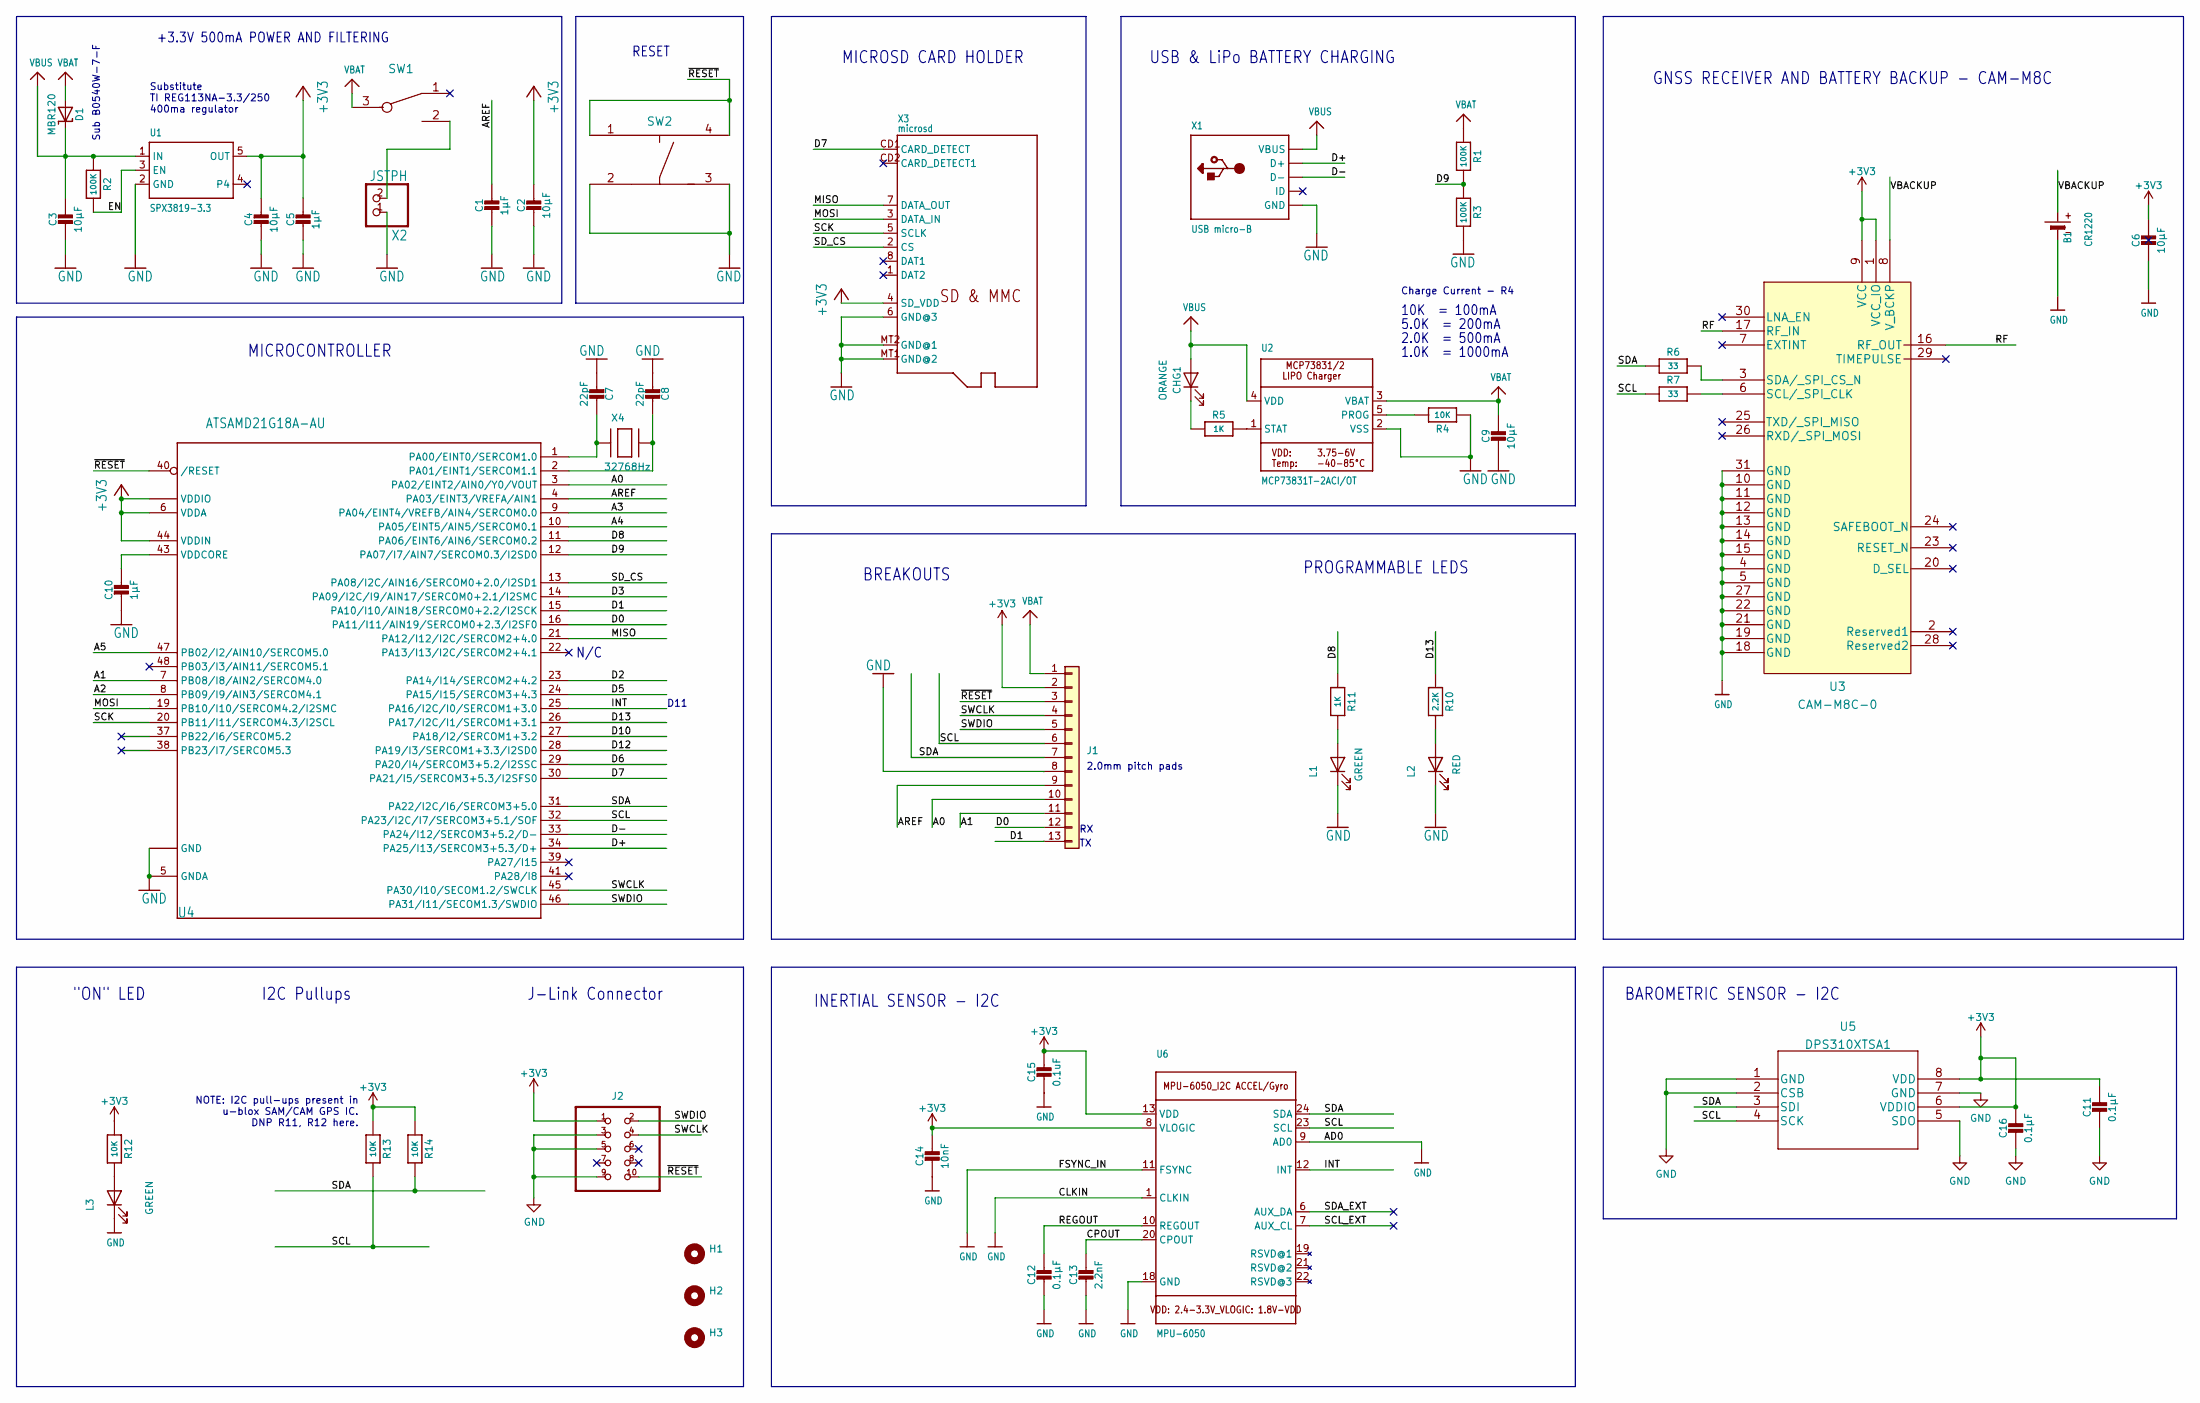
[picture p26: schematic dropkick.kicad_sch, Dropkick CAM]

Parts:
B1: CR1220; CR1220-2; Manufacturer Part 1056TR
C1, C5, C10: 1µF; C_0603_1608Metric
C2, C3, C4, C6, C9: 10µF; C_0805_2012Metric; Manufacturer Part C0805C106K8RACTU
C7, C8: 22pF; C_0603_1608Metric; Manufacturer Part 06035U220FAT2A
C11, C12, C16: 0.1µF; C_0603_1608Metric; Manufacturer Part VJ0603Y104JXXAC
C13: 2.2nF; C_0603_1608Metric; Manufacturer Part C0603C222K1HACAUTO
C14: 10nF; C_0603_1608Metric; Manufacturer Part C0603C222K1HACAUTO
C15: 0.1uF; C_0603_1608Metric; Manufacturer Part C0603C222K1HACAUTO
CHG1: ORANGE; LED_0603_1608Metric; Manufacturer Part AA1112H-TR
D1: MBR120; SOD-123; Manufacturer Part PMEG2005EGWX
H1, H2, H3: MountingHole; MOUNTINGHOLE_2.5_PLATED
J1: Conn_01x13; PinSocket_1x13_P2.00mm_Vertical
J2: 3221-10-0300-00-TR; Manufacturer Part 3221-10-0300-00-TR
L1, L3: GREEN; LED_0603_1608Metric; Manufacturer Part LTST-S270KGKT
L2: RED; LED_0603_1608Metric; Manufacturer Part LTST-S270KRKT
R1, R2, R3: 100K; R_0603_1608Metric; Manufacturer Part TNPW0603100KBEEA
R4, R12, R13, R14: 10K; R_0603_1608Metric
R5, R11: 1K; R_0603_1608Metric
R6, R7: 33; R_0402_1005Metric
R10: 2.2K; R_0603_1608Metric; Manufacturer Part CRCW06032K20FKEAHP
SW1: 450405020524; Manufacturer Part 450405020524
SW2: KMR211NG_LFS; KMR211NG LFS; Manufacturer Part KMR211NG LFS
U1: SPX3819-3.3; SOT23-5; Manufacturer Part SPX3819M5-L-3-3/TR
U2: MCP73831T-2ACI/OT; SOT23-5; Manufacturer Part MCP73831T-2ACI/OT
U3: CAM-M8C-0; Manufacturer Part CAM-M8C-0
U4: ATSAMD21G18A-AU; ATSAMD21G15B-AU; Manufacturer Part ATSAMD21G18A-AU
U5: DPS310XTSA1; Manufacturer Part DPS310XTSA1
U6: MPU-6050; MPU6XXX_QFN24_4MM_SMSC; Manufacturer Part MPU-6050
X1: USB micro-B; 4UCONN_20329_V2; Manufacturer Part 4UCONN_20329_V2
X2: JSTPH; JSTPH2; Manufacturer Part S2B-PH-SM4-TB
X3: microsd; MICROSD; Manufacturer Part MEM2061-01-188-00-A
X4: 32768Hz; XTAL3215; Manufacturer Part FC-135 32.7680KA-A5

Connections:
+3V3: C2.1, C4.1, C5.1, C6.1, C11.1, C14.1, C15.1, C16.1, J1.2, J2.1, R12.1, R13.1, R14.1, U1.5 (OUT), U3.1 (VCC_IO), U3.9 (VCC), U4.6 (VDDA), U4.17 (VDDIO), U4.36 (VDDIO), U4.44 (VDDIN), U5.6 (VDDIO), U5.8 (VDD), U6.8 (VLOGIC), U6.13 (VDD), X3.4 (SD_VDD)
/A0: J1.10, U4.3 (PA02/EINT2/AIN0/Y0/VOUT)
/A1: J1.11, U4.7 (PB08/I8/AIN2/SERCOM4.0)
/A2: U4.8 (PB09/I9/AIN3/SERCOM4.1)
/A3: U4.9 (PA04/EINT4/VREFB/AIN4/SERCOM0.0)
/A4: U4.10 (PA05/EINT5/AIN5/SERCOM0.1)
/A5: U4.47 (PB02/I2/AIN10/SERCOM5.0)
/AREF: C1.1, J1.9, U4.4 (PA03/EINT3/VREFA/AIN1)
/CPOUT: C13.1, U6.20 (CPOUT)
/D0: J1.12, U4.16 (PA11/I11/AIN19/SERCOM0+2.3/I2SF0)
/D1: J1.13, U4.15 (PA10/I10/AIN18/SERCOM0+2.2/I2SCK)
/D2: U4.23 (PA14/I14/SERCOM2+4.2)
/D3: U4.14 (PA09/I2C/I9/AIN17/SERCOM0+2.1/I2SMC)
/D5: U4.24 (PA15/I15/SERCOM3+4.3)
/D6: U4.29 (PA20/I4/SERCOM3+5.2/I2SSC)
/D7: U4.30 (PA21/I5/SERCOM3+5.3/I2SFS0), X3.CD1 (CARD_DETECT)
/D8: R11.1, U4.11 (PA06/EINT6/AIN6/SERCOM0.2)
/D9: R1.2, R3.1, U4.12 (PA07/I7/AIN7/SERCOM0.3/I2SD0)
/D10: U4.27 (PA18/I2/SERCOM1+3.2)
/D12: U4.28 (PA19/I3/SERCOM1+3.3/I2SD0)
/D13: R10.1, U4.26 (PA17/I2C/I1/SERCOM1+3.1)
/D+: U4.34 (PA25/I13/SERCOM3+5.3/D+), X1.D+
/D-: U4.33 (PA24/I12/SERCOM3+5.2/D-), X1.D-
/EN: R2.2, U1.3 (EN)
/INT: U4.25 (PA16/I2C/I0/SERCOM1+3.0), U6.12 (INT)
/MISO: U4.21 (PA12/I12/I2C/SERCOM2+4.0), X3.7 (DATA_OUT)
/MOSI: U4.19 (PB10/I10/SERCOM4.2/I2SMC), X3.3 (DATA_IN)
/REGOUT: C12.1, U6.10 (REGOUT)
/RF: U3.16 (RF_OUT), U3.17 (RF_IN)
/SCK: U4.20 (PB11/I11/SERCOM4.3/I2SCL), X3.5 (SCLK)
/SCL: J1.6, R7.1, R13.2, U4.32 (PA23/I2C/I7/SERCOM3+5.1/SOF), U5.4 (SCK), U6.23 (SCL)
/SCL_EXT: U6.7 (AUX_CL)
/SDA: J1.7, R6.1, R14.2, U4.31 (PA22/I2C/I6/SERCOM3+5.0), U5.3 (SDI), U6.24 (SDA)
/SDA_EXT: U6.6 (AUX_DA)
/SD_CS: U4.13 (PA08/I2C/AIN16/SERCOM0+2.0/I2SD1), X3.2 (CS)
/SWCLK: J1.4, J2.4, U4.45 (PA30/I10/SECOM1.2/SWCLK)
/SWDIO: J1.5, J2.2, U4.46 (PA31/I11/SECOM1.3/SWDIO)
/VBACKUP: B1.+, U3.8 (V_BCKP)
/~RESET: J1.3, J2.10, SW2.1, SW2.4, U4.40 (/RESET)
GND: B1.-, C1.2, C2.2, C3.2, C4.2, C5.2, C6.2, C7.2, C8.2, C9.2, C10.2, C11.2, C12.2, C13.2, C14.2, C15.2, C16.2, J1.8, J2.3, J2.5, J2.9, L1.1 (K), L2.1 (K), L3.1 (K), R3.2, R4.2, SW2.2, SW2.3, U1.2 (GND), U2.2 (VSS), U3.4 (GND), U3.5 (GND), U3.10 (GND), U3.11 (GND), U3.12 (GND), U3.13 (GND), U3.14 (GND), U3.15 (GND), U3.18 (GND), U3.19 (GND), U3.21 (GND), U3.22 (GND), U3.27 (GND), U3.31 (GND), U4.5 (GNDA), U4.18 (GND), U4.35 (GND), U4.42 (GND), U5.1 (GND), U5.2 (CSB), U5.5 (SDO), U5.7 (GND), U6.1 (CLKIN), U6.9 (AD0), U6.11 (FSYNC), U6.18 (GND), X1.BASE@1 (GND), X1.BASE@2 (GND), X1.GND, X1.SPRT@1 (GND), X1.SPRT@2 (GND), X1.SPRT@3 (GND), X1.SPRT@4 (GND), X2.1, X3.6 (GND@3), X3.MT1 (GND@2), X3.MT2 (GND@1)
unnamed: CHG1.1 (K), R5.1
unnamed: L1.2 (A), R11.2
unnamed: L2.2 (A), R10.2
unnamed: L3.2 (A), R12.2
unnamed: SW1.2, X2.2
unnamed: R4.1, U2.5 (PROG)
unnamed: R5.2, U2.1 (STAT)
unnamed: R7.2, U3.6 (SCL/_SPI_CLK)
unnamed: R6.2, U3.3 (SDA/_SPI_CS_N)
unnamed: C7.1, U4.1 (PA00/EINT0/SERCOM1.0), X4.P$1
unnamed: C8.1, U4.2 (PA01/EINT1/SERCOM1.1), X4.P$2
unnamed: C10.1, U4.43 (VDDCORE)
VBAT: C9.1, D1.A, J1.1, R1.1, SW1.3, U2.3 (VBAT)
VBUS: C3.1, CHG1.2 (A), D1.C, R2.1, U1.1 (IN), U2.4 (VDD), X1.VBUS

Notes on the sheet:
BAROMETRIC SENSOR - I2C
GNSS RECEIVER AND BATTERY BACKUP - CAM-M8C
"ON" LED
N/C
I2C Pullups
10K = 100mA
INERTIAL SENSOR - I2C
MICROCONTROLLER
1.0K = 1000mA
Charge Current - R4
5.0K = 200mA
BREAKOUTS
RESET
D11
+3.3V 500mA POWER AND FILTERING
J-Link Connector
Substitute TI REG113NA-3.3/250 400ma regulator
PROGRAMMABLE LEDS
2.0mm pitch pads
2.0K = 500mA
MICROSD CARD HOLDER
USB & LiPo BATTERY CHARGING
NOTE: I2C pull-ups present in u-blox SAM/CAM GPS IC. DNP R11, R12 here.
Sub B0540W-7-F

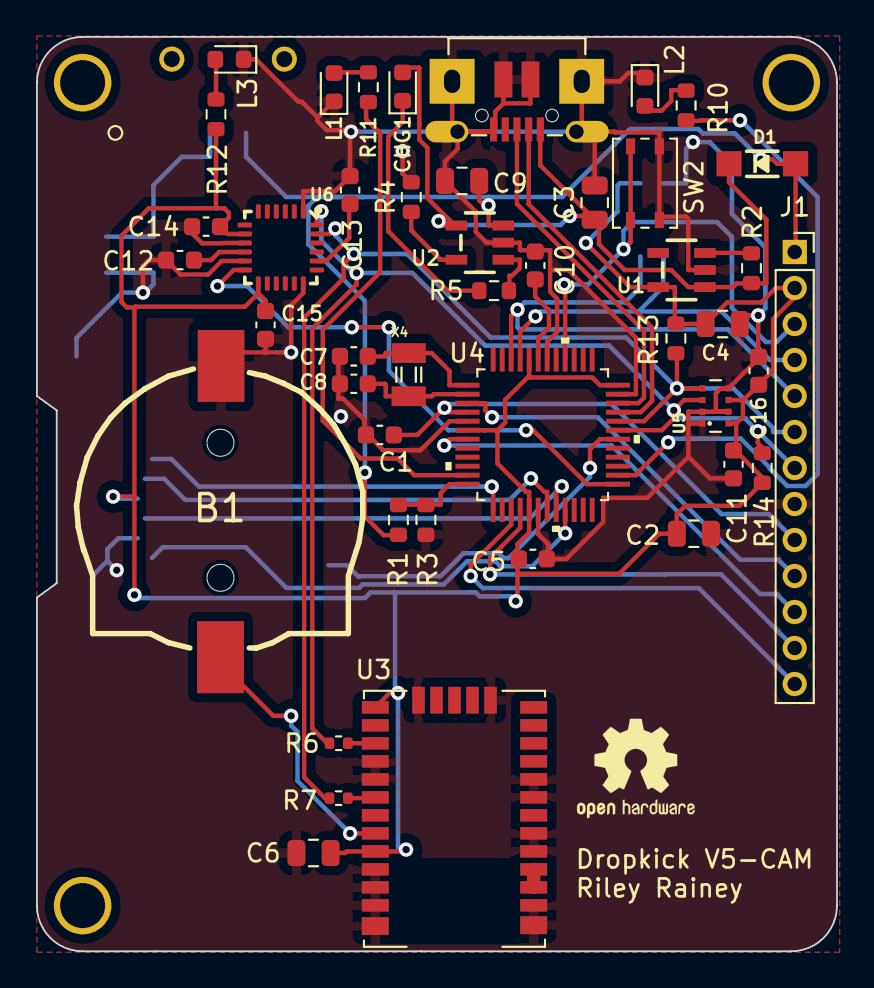
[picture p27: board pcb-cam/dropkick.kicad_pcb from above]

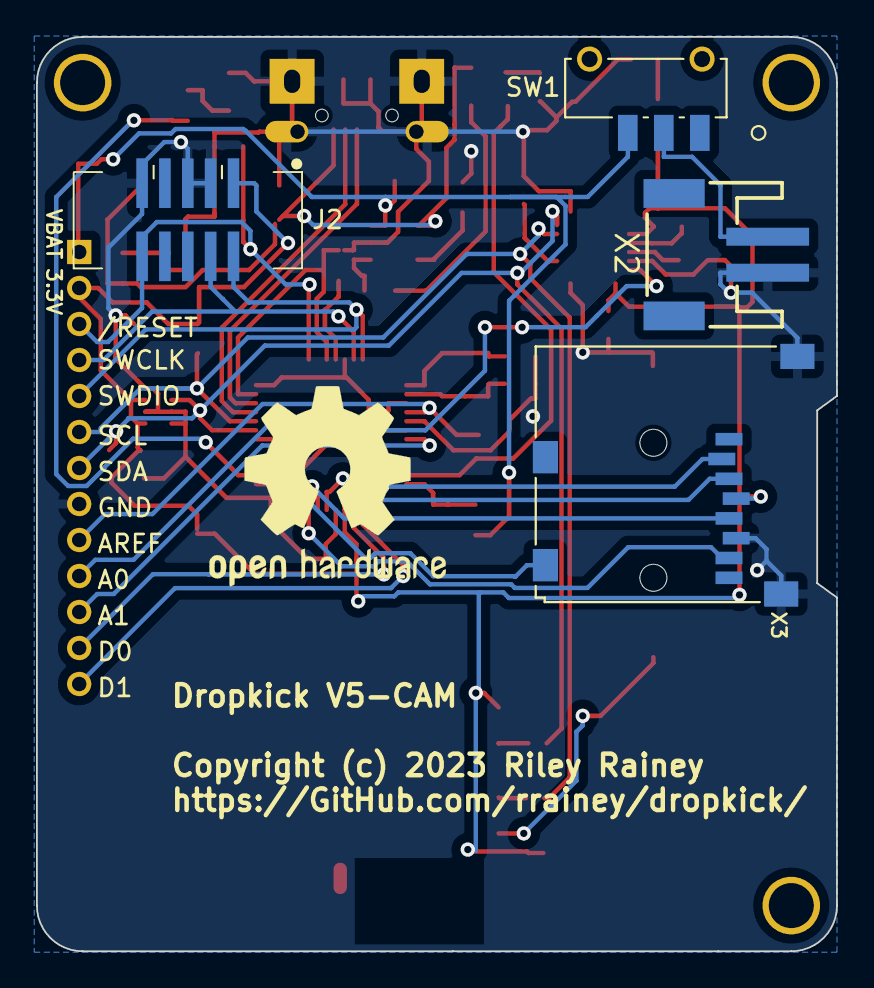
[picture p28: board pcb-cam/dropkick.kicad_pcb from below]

Board: 2 copper layers, 44.5 x 50.8 mm, 53 parts (5 on the bottom side), 42 nets.

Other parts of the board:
REF1: OSHW-Logo2_7.3x6mm_SilkScreen
REF2: OSHW-Logo2_14.6x12mm_SilkScreen

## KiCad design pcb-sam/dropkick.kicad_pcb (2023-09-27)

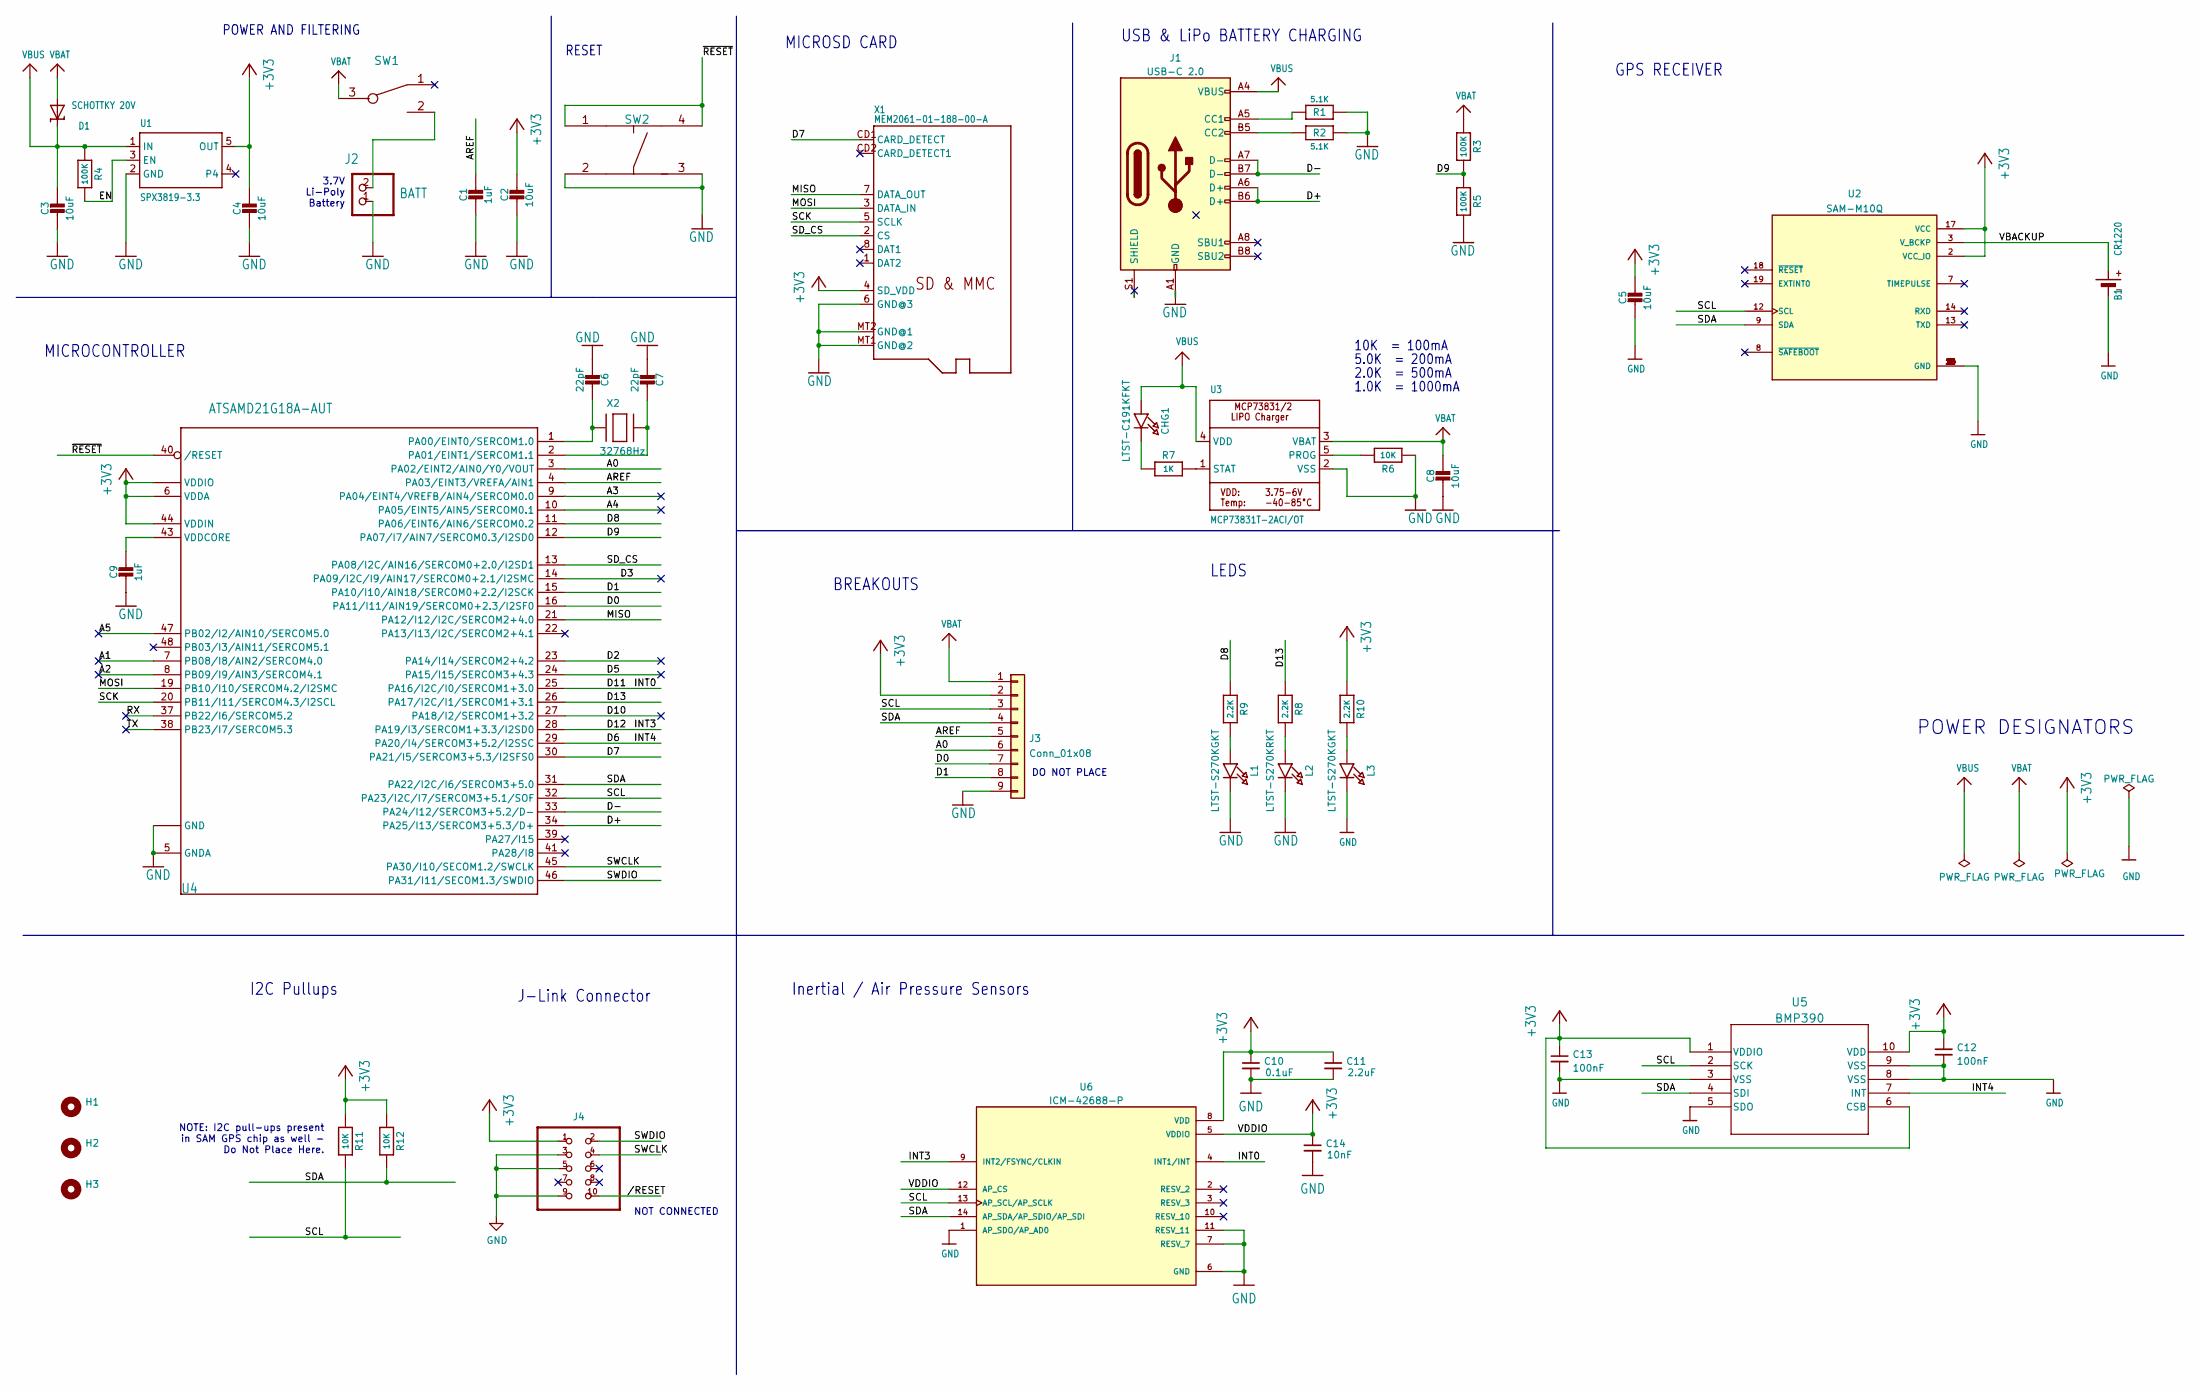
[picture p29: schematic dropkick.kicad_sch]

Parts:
B1: CR1220; CR1220-2; MPN 1056TR
C1, C9: 1uF; C_0603_1608Metric
C2, C3, C4, C5, C8: 10uF; C_0805_2012Metric
C6, C7: 22pF; C_0603_1608Metric
C10: 0.1uF; C_0603_1608Metric
C11: 2.2uF; C_0603_1608Metric
C12, C13: 100nF; C_0603_1608Metric
C14: 10nF; C_0603_1608Metric
CHG1: LTST-C191KFKT; CHIPLED_0603_NOOUTLINE; MPN LTST-C191KFKT
D1: SCHOTTKY 20V; D_SOD-123F; MPN SM5817PL-TP
H1, H2, H3: MountingHole; MOUNTINGHOLE_2.5_PLATED
J1: USB-C 2.0; USB_C_Receptacle_GCT_USB4085; MPN USB4085-GF-A
J2: BATT; JSTPH2; MPN S2B-PH-SM4-TB
J3: Conn_01x08; PinHeader_1x09_P2.54mm_Vertical; MPN DNP
J4: 3221-10-0300-00-TR; MPN 3221-10-0300-00-TR
L1, L3: LTST-S270KGKT; CHIPLED_0603_NOOUTLINE; MPN LTST-S270KGKT
L2: LTST-S270KRKT; CHIPLED_0603_NOOUTLINE; MPN LTST-S270KRKT
R1, R2: 5.1K; R_0402_1005Metric
R3, R4, R5: 100K; R_0603_1608Metric
R6, R11, R12: 10K; R_0603_1608Metric
R7: 1K; R_0603_1608Metric
R8, R9, R10: 2.2K; R_0603_1608Metric
SW1: 450405020524; MPN 450405020524
SW2: KMR211NG_LFS; KMR211NG LFS; MPN KMR211NG_LFS
U1: SPX3819-3.3; SOT23-5; MPN SPX3819-3.3
U2: SAM-M10Q; MODULE_SAM-M8Q-0-10; PARTREV R07
U3: MCP73831T-2ACI/OT; SOT23-5; MPN MCP73831T-2ACI/OT
U4: ATSAMD21G18A-AUT; ATSAMD21G15B-AU; MPN ATSAMD21G18A-AUT
U5: BMP390; LGA10_BMP390_BOS
U6: ICM-42688-P; PQFN50P300X250X97-14N; PARTREV 1.2
X1: MEM2061-01-188-00-A; MICROSD; MPN MEM2061-01-188-00-A
X2: 32768Hz; XTAL3215; MPN FC-135 32.7680KA-A5

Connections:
+3V3: C2.1, C4.1, C5.1, C10.1, C11.1, C12.1, C13.1, C14.1, J3.2, J4.1, R10.1, R11.1, R12.1, U1.5 (OUT), U2.2 (VCC_IO), U2.17 (VCC), U4.6 (VDDA), U4.17 (VDDIO), U4.36 (VDDIO), U4.44 (VDDIN), U5.1 (VDDIO), U5.6 (CSB), U5.10 (VDD), U6.5 (VDDIO), U6.8 (VDD), U6.12 (AP_CS), X1.4 (SD_VDD)
/A0: J3.6, U4.3 (PA02/EINT2/AIN0/Y0/VOUT)
/A1: U4.7 (PB08/I8/AIN2/SERCOM4.0)
/A2: U4.8 (PB09/I9/AIN3/SERCOM4.1)
/A3: U4.9 (PA04/EINT4/VREFB/AIN4/SERCOM0.0)
/A4: U4.10 (PA05/EINT5/AIN5/SERCOM0.1)
/A5: U4.47 (PB02/I2/AIN10/SERCOM5.0)
/AREF: C1.1, J3.5, U4.4 (PA03/EINT3/VREFA/AIN1)
/D0: J3.7, U4.16 (PA11/I11/AIN19/SERCOM0+2.3/I2SF0)
/D1: J3.8, U4.15 (PA10/I10/AIN18/SERCOM0+2.2/I2SCK)
/D2: U4.23 (PA14/I14/SERCOM2+4.2)
/D3: U4.14 (PA09/I2C/I9/AIN17/SERCOM0+2.1/I2SMC)
/D5: U4.24 (PA15/I15/SERCOM3+4.3)
/D6: U4.29 (PA20/I4/SERCOM3+5.2/I2SSC), U5.7 (INT)
/D7: U4.30 (PA21/I5/SERCOM3+5.3/I2SFS0), X1.CD1 (CARD_DETECT)
/D8: R9.1, U4.11 (PA06/EINT6/AIN6/SERCOM0.2)
/D9: R3.2, R5.1, U4.12 (PA07/I7/AIN7/SERCOM0.3/I2SD0)
/D10: U4.27 (PA18/I2/SERCOM1+3.2)
/D11: U4.25 (PA16/I2C/I0/SERCOM1+3.0), U6.4 (INT1/INT)
/D12: U4.28 (PA19/I3/SERCOM1+3.3/I2SD0), U6.9 (INT2/FSYNC/CLKIN)
/D13: R8.1, U4.26 (PA17/I2C/I1/SERCOM1+3.1)
/D+: J1.A6 (D+), J1.B6 (D+), U4.34 (PA25/I13/SERCOM3+5.3/D+)
/D-: J1.A7 (D-), J1.B7 (D-), U4.33 (PA24/I12/SERCOM3+5.2/D-)
/EN: R4.2, U1.3 (EN)
/MISO: U4.21 (PA12/I12/I2C/SERCOM2+4.0), X1.7 (DATA_OUT)
/MOSI: U4.19 (PB10/I10/SERCOM4.2/I2SMC), X1.3 (DATA_IN)
/RX: U4.37 (PB22/I6/SERCOM5.2)
/SCK: U4.20 (PB11/I11/SERCOM4.3/I2SCL), X1.5 (SCLK)
/SCL: J3.3, R11.2, U2.12 (SCL), U4.32 (PA23/I2C/I7/SERCOM3+5.1/SOF), U5.2 (SCK), U6.13 (AP_SCL/AP_SCLK)
/SDA: J3.4, R12.2, U2.9 (SDA), U4.31 (PA22/I2C/I6/SERCOM3+5.0), U5.4 (SDI), U6.14 (AP_SDA/AP_SDIO/AP_SDI)
/SD_CS: U4.13 (PA08/I2C/AIN16/SERCOM0+2.0/I2SD1), X1.2 (CS)
/SWCLK: J4.4, U4.45 (PA30/I10/SECOM1.2/SWCLK)
/SWDIO: J4.2, U4.46 (PA31/I11/SECOM1.3/SWDIO)
/TX: U4.38 (PB23/I7/SERCOM5.3)
/VBACKUP: B1.+, U2.3 (V_BCKP)
//RESET: J4.10
/~RESET: SW2.1, SW2.4, U4.40 (/RESET)
GND: B1.-, C1.2, C2.2, C3.2, C4.2, C5.2, C6.2, C7.2, C8.2, C9.2, C10.2, C11.2, C12.2, C13.2, C14.2, J1.A1 (GND), J1.A12 (GND), J1.B1 (GND), J1.B12 (GND), J2.1, J3.9, J4.3, J4.5, J4.9, L1.C, L2.C, L3.C, R1.2, R2.2, R5.2, R6.2, SW2.2, SW2.3, U1.2 (GND), U2.1 (GND), U2.4 (GND), U2.5 (GND), U2.6 (GND), U2.10 (GND), U2.11 (GND), U2.15 (GND), U2.16 (GND), U2.20 (GND), U3.2 (VSS), U4.5 (GNDA), U4.18 (GND), U4.35 (GND), U4.42 (GND), U5.3 (VSS), U5.5 (SDO), U5.8 (VSS), U5.9 (VSS), U6.1 (AP_SDO/AP_AD0), U6.6 (GND), U6.7 (RESV_7), U6.11 (RESV_11), X1.6 (GND@3), X1.MT1 (GND@2), X1.MT2 (GND@1)
unnamed: C6.1, U4.1 (PA00/EINT0/SERCOM1.0), X2.P$1
unnamed: C7.1, U4.2 (PA01/EINT1/SERCOM1.1), X2.P$2
unnamed: C9.1, U4.43 (VDDCORE)
unnamed: CHG1.C, R7.1
unnamed: J1.A5 (CC1), R1.1
unnamed: J1.B5 (CC2), R2.1
unnamed: J2.2, SW1.2
unnamed: L1.A, R9.2
unnamed: L2.A, R8.2
unnamed: L3.A, R10.2
unnamed: R6.1, U3.5 (PROG)
unnamed: R7.2, U3.1 (STAT)
VBAT: C8.1, D1.2, J3.1, R3.1, SW1.3, U3.3 (VBAT)
VBUS: C3.1, CHG1.A, D1.1, J1.A4 (VBUS), J1.A9 (VBUS), J1.B4 (VBUS), J1.B9 (VBUS), R4.1, U1.1 (IN), U3.4 (VDD)

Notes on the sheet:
GPS RECEIVER
POWER DESIGNATORS
NOT CONNECTED
I2C Pullups
10K = 100mA
Inertial / Air Pressure Sensors
MICROCONTROLLER
1.0K = 1000mA
5.0K = 200mA
BREAKOUTS
RESET
POWER AND FILTERING
J-Link Connector
DO NOT PLACE
LEDS
3.7V Li-Poly Battery
2.0K = 500mA
MICROSD CARD
USB & LiPo BATTERY CHARGING
NOTE: I2C pull-ups present in SAM GPS chip as well - Do Not Place Here.

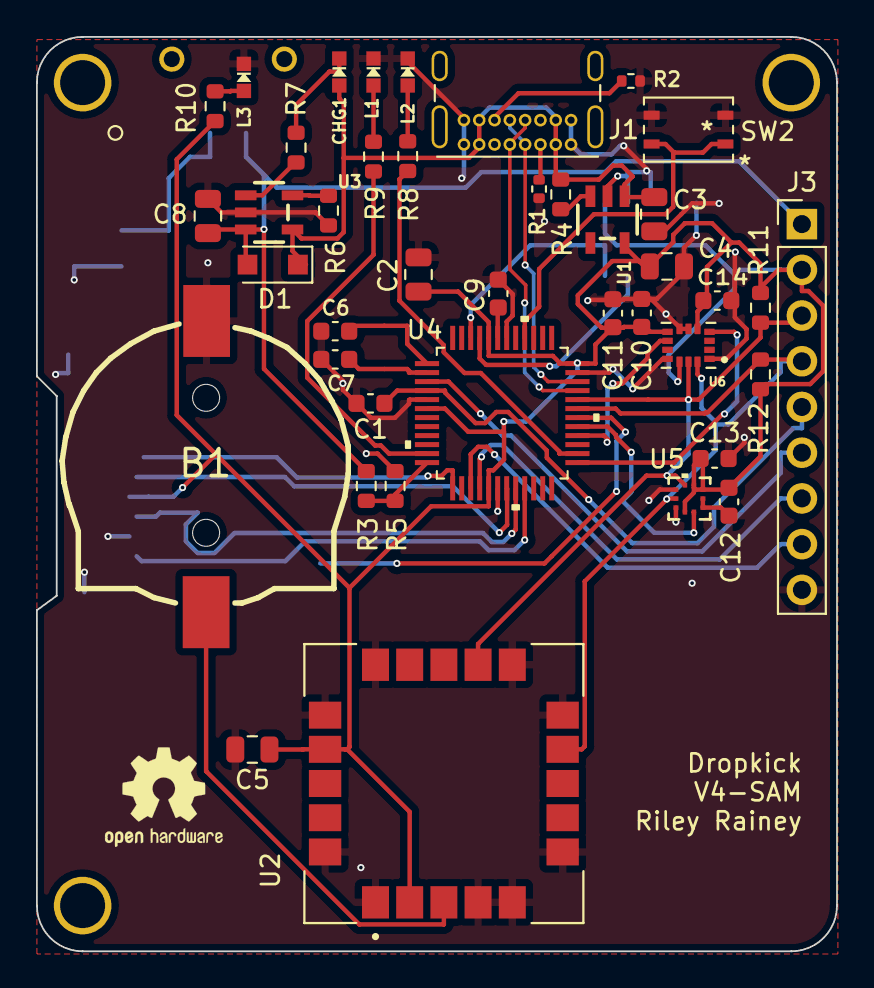
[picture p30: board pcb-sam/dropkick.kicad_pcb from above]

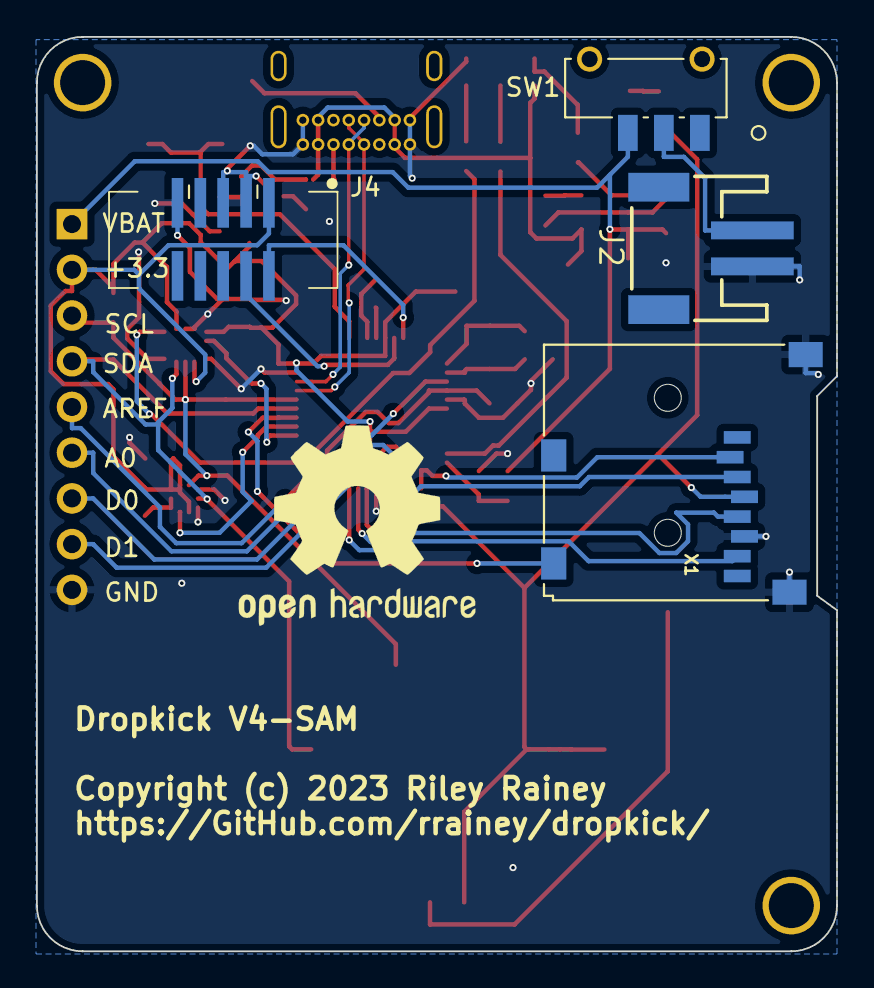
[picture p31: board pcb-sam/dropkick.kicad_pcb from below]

Board: 2 copper layers, 44.5 x 50.8 mm, 50 parts (5 on the bottom side), 40 nets.

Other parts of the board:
REF1: OSHW-Logo2_14.6x12mm_SilkScreen
REF2: OSHW-Logo2_7.3x6mm_SilkScreen

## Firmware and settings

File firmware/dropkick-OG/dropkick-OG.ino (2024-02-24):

/* 
 * This file is part of the Kick distribution (https://github.com/rrainey/dropkick
 * Copyright (c) 2022 Riley Rainey
 * 
 * =========================================================================
 * 
 * COMPATIBILITY
 * 
 * This sketch is designed for use with V2-SAM and all CAM board variants
 * 
 * =========================================================================
 * 
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
 * You should have received a copy of the GNU General Public License 
 * along with this program. If not, see <http://www.gnu.org/licenses/>.
 */

#include <Adafruit_DPS310.h>
#include <Adafruit_MPU6050.h>
#include <Adafruit_Sensor.h>
#include <SPI.h>
#include <SDPlus.h>
#include <Adafruit_TinyUSB.h>

#include <SparkFun_u-blox_GNSS_Arduino_Library.h> //Click here to get the library: http://librarymanager/All#SparkFun_u-blox_GNSS

SFE_UBLOX_GNSS myGNSS;

#include <MicroNMEA.h> //http://librarymanager/All#MicroNMEA
char nmeaBuffer[100];
MicroNMEA nmea(nmeaBuffer, sizeof(nmeaBuffer));

Adafruit_USBD_MSC usb_msc;

#define APP_STRING  "Dropkick, version 0.55"
#define LOG_VERSION 1
#define NMEA_APP_STRING "$PVER,\"Dropkick, version 0.55\",55"

/*
 * Last built with Arduino version 1.8.19
 * 
 * Change History affecting sensor output and log file contents
 * 
 * Version 55:
 *    Disable NMEA satellite status sentences when in higher GNSS position polling rates
 *    
 * Version 54:
 *    5 Hz GNSS message rate when in freefall till landing.
 * 
 * Version 53:
 *    u-blox Dynamic Platform Mode now set to Airborne 2g 
 *    (see pg. 21 of https://content.u-blox.com/sites/default/files/products/documents/u-blox8-M8_ReceiverDescrProtSpec_UBX-13003221.pdf)
 *    Logging GNSS fix rate raised from 2 to 4 fixes per second.
 *    millis() times appearing in a log file are now relative to the start of logging for the file
 *    Boot initialization now only waits for 20 seconds for a USB connection (was 30 seconds)
 */

/*
 * I2C peripheral addresses valid for the V2-SAM and V3-SAM PCBs
 */
#define GPS_I2C_ADDR     0x42
#define DPS310_I2C_ADDR  0x76
#define MPU6050_I2C_ADDR 0x69

/**
 * Fatal error codes (to be implemented)
 * 
 * 1 - no SD card
 * 2 - altitude sensor fail
 * 3 - IMU sensor fail
 */

/*
 * Operating mode
 */
#define OPS_FLIGHT        0  // normal mode; altimeter used to detect motion
#define OPS_STATIC_TEST   1  // for testing; time based simulation of vertical motion (preferred test mode)
#define OPS_GROUND_TEST   2  // for testing; uses GPS horizontal movement as an analogue to altitude changes

/*
 * Set opertaing mode for this build of the firmware here
 */
#define OPS_MODE OPS_FLIGHT

#if (OPS_MODE == OPS_STATIC_TEST) 
//#include "1976AtmosphericModel.h"

//sim1976AtmosphericModel g_atm;

#endif

#define TEST_SPEED_THRESHOLD_KTS     6.0
#define OPS_HDOT_THRESHOLD_FPM       300
#define OPS_HDOT_LAND_THRESHOLD_FPM  100
#define OPS_HDOT_JUMPING_FPM         -800

/*
 * Minutes to milliseconds
 */
#define MINtoMS(x) ((x) * 60 * 1000)

/*
 * Automatic jump logging
 * Generate a unique log file for each jump.
 * Log file contains GPS NMEA CSV records along with extra sensor data records in quasi-NMEA format
 * 
 * State 0: WAIT - gather baseline surface elevation information; compute HDOT_fps
 *                 GNSS update rate @ 1Hz
 * 
 * State 1: IN_FLIGHT (enter this state when HDOT_fpm indicates >= 300 fpm climb), 
 *                   GNSS update rate @ 1Hz, compute HDOT_fps, start logging if not already)
 *
 * State 2: JUMPING (enter this state whenever HDOT_FPM < -800 fpm)
 *                  GNSS update rate increases to 2Hz, compute HDOT_fps, start logging if not already)
 *                   
 *                   
 * State 3: LANDED1  like state 2 - if any conditions are vioated, return to state 2(JUMPING), 
 *                   go to state 0 when timer 1 reaches 60 seconds, set GNSS update rate set to 1Hz, close logfile
 *                   log data otherwise
 */

#define STATE_WAIT       0
#define STATE_IN_FLIGHT  1
#define STATE_JUMPING    2
#define STATE_LANDED_1   3
#define STATE_LANDED_2   4

int nAppState;

#define BLINK_STATE_OFF     0
#define BLINK_STATE_LOGGING 1
#define BLINK_STATE_BATTERY 2

int blinkState = BLINK_STATE_OFF;

bool bBatteryAlarm = false;
float measuredBattery_volts;

/*
 * LiPoly battery is rated at 3.7V
 */
#define LOWBATT_THRESHOLD 3.55

/*
 * Estimated MSL altitude, based on standard day pressure @ sea level
 */
int nH_feet = 0;

/*
 * Estimated rate of climb (fpm)
 */
int nHDot_fpm = 0;
/*
 * Estimated ground elevation, ft
 * 
 * Computed while in WAIT state.
 */
int nHGround_feet = 0;

#define NUM_H_SAMPLES 5
int nHSample[NUM_H_SAMPLES];
int nHDotSample[NUM_H_SAMPLES];
int nNextHSample = 0;
uint32_t ulLastHSampleMillis;

uint32_t ulLogfileOriginMillis;

boolean bFirstPressureSample = true;

/**
 * Currently unused.
 */
int computAvgHDot() {
  int i;
  int sum;
  for(i=0; i<NUM_H_SAMPLES; ++i) {
    sum += nHDotSample[i];
  }
  return sum / 5;
}

/**
 * Use pressure altitude samples to estimate rate of climb.
 * 
 * Rate of climb is re-estimated every 10 seconds.
 */
void updateHDot(float H_feet) {

  uint32_t ulMillis = millis();
  int nLastHSample_feet;
  int nInterval_ms =  ulMillis - ulLastHSampleMillis;

  /* update HDot every ten seconds */
  if (nInterval_ms > 10000) {
    if (!bFirstPressureSample) {
      if (nNextHSample == 0) {
        nLastHSample_feet = nHSample[NUM_H_SAMPLES-1];
      }
      else {
        nLastHSample_feet = nHSample[nNextHSample-1];
      }
      nHSample[nNextHSample] = H_feet;
      nHDotSample[nNextHSample] = (((long) H_feet - nLastHSample_feet) * 60000L) / nInterval_ms;
      nHDot_fpm = nHDotSample[nNextHSample];
    }
    else {
      bFirstPressureSample = false;
      nHSample[nNextHSample] = H_feet;
      nHDotSample[nNextHSample] = 0;
      nHDot_fpm = 0;
    }

    ulLastHSampleMillis = ulMillis;
    if (++nNextHSample >= NUM_H_SAMPLES) {
      nNextHSample = 0;
    }
  }
}

/*
 * I2C connection to the MPU-6050 IMU
 */
Adafruit_MPU6050 mpu;

bool imuPresent = false;

#define SEALEVELPRESSURE_HPA (1013.25)

Adafruit_DPS310 dps;
Adafruit_Sensor *dps_temp = dps.getTemperatureSensor();
Adafruit_Sensor *dps_pressure = dps.getPressureSensor();

/*
 * Adalogger M0 hardware definitions
 * 
 * See https://learn.adafruit.com/adafruit-feather-m0-adalogger/pinouts
 */
#define VBATPIN       A7
#define RED_LED       13
#define GREEN_SD_LED   8
#define SD_CHIP_SELECT 4

File logFile;

char logpath[32];

/*
 * Records last millis() time when timers were updated in
 * the main loop.
 */
uint32_t lastTime_ms = 0;

/*
 * Records last millis() time for start of NMEA sentence arrival. 
 * Useful to sync millis() time with GPS clock.
 */
uint32_t lastNMEATime_ms = 0;

/*
 * Set up timers
 * 
 * Timer 1: used in landing state machine (OFF initially)
 * 
 * Timer 2: periodic check of battery state
 * 
 * Timer 3: blink controller for RED LED  (OFF initially)
 * 
 * Timer 4: IMU sensor logging interval timer  (OFF initially)
 * 
 * Timer 5: Periodic SD-card log file flushing  (OFF initially)
 */

#define TIMER1_INTERVAL_MS 30000

bool bTimer1Active = false;
int32_t timer1_ms = 0;

#define TIMER2_INTERVAL_MS 30000

bool bTimer2Active = true;
int32_t timer2_ms = TIMER2_INTERVAL_MS;

#define TIMER3_ON_INTERVAL_MS     750
#define TIMER3_OFF_INTERVAL_1_MS  750 // off interval when signaling battery low
#define TIMER3_OFF_INTERVAL_2_MS  (3000 - TIMER3_ON_INTERVAL_MS) // off interval for flight mode

bool bTimer3Active = false;
int32_t timer3_ms = 0;

#define TIMER4_INTERVAL_MS 25  // 40Hz

bool bTimer4Active = false;
int32_t timer4_ms = 0;

#define TIMER5_INTERVAL_MS 10000

bool bTimer5Active = false;
int32_t timer5_ms = 0;

int redLEDState = LOW;

// For debugging
bool printNMEA = false;

/**
 * Control RED (blinking) LED
 * This LED is locted to the left of the USB connector on
 * the Adalogger
 */
void setBlinkState( int newState ) {

  switch ( blinkState ) {

  case BLINK_STATE_OFF:
    // Was off, now on?
    if (newState != BLINK_STATE_OFF ) {
      bTimer3Active = true;
      timer3_ms = TIMER3_ON_INTERVAL_MS;
      redLEDState = HIGH;
    }
    break;
    
  case BLINK_STATE_LOGGING:
    if (newState == BLINK_STATE_BATTERY) {
      bTimer3Active = true;
      timer3_ms = TIMER3_ON_INTERVAL_MS;
      redLEDState = HIGH;
    }
    else if (newState == BLINK_STATE_OFF) {
        bTimer3Active = false;
        redLEDState = LOW;
     }
     break;
     
  case BLINK_STATE_BATTERY:
    if (newState == BLINK_STATE_OFF) {
      bTimer3Active = false;
      redLEDState = LOW;
    }
    else {
      // update state, but let blinking logic handle the transition
    }
    break;
  }

  // Update state and LED
  blinkState = newState;
  digitalWrite( RED_LED, redLEDState );
}

char * generateLogname(char *gname) 
{
    char * result = NULL;
    int i;
    for (i=0; true; i++) {
      sprintf (gname, "log%05d.txt", i);
   
      if (!SD.exists(gname)) {
          result = gname;
          break;
      }
    }

    return result;
}

void updateTestStateMachine() {

  /**
   * State machine appropriate for ground testing
   */
  switch (nAppState) {

  case STATE_WAIT:
    if (nmea.isValid() && nmea.getSpeed() >= TEST_SPEED_THRESHOLD_KTS*1000) {

      Serial.println("Switching to STATE_IN_FLIGHT");
      
      // open log file
      generateLogname( logpath );
      logFile = SD.open( logpath, FILE_WRITE );

      logFile.println( NMEA_APP_STRING );

      // Activate altitude / battery sensor logging
      bTimer4Active = true;
      timer4_ms = TIMER4_INTERVAL_MS;

      // Activate periodic log file flushing
      startLogFileFlushing();

      // set nav update rate to 4Hz
      myGNSS.setNavigationFrequency(4);

      // Activate "in flight" LED blinking
      setBlinkState ( BLINK_STATE_LOGGING );
      
      nAppState = STATE_IN_FLIGHT;
    }
    break;

  case STATE_IN_FLIGHT:
    {

      if (nmea.isValid() && nmea.getSpeed() < TEST_SPEED_THRESHOLD_KTS*1000) {
        Serial.println("Switching to STATE_LANDED_1");
        nAppState = STATE_LANDED_1;
        timer1_ms = TIMER1_INTERVAL_MS;
        bTimer1Active = true;
      }
    }
    break;

  case STATE_LANDED_1:
    {

      if (nmea.isValid() && nmea.getSpeed() >= TEST_SPEED_THRESHOLD_KTS*1000) {
        Serial.println("Switching to STATE_IN_FLIGHT");
        nAppState = STATE_IN_FLIGHT;
        bTimer1Active = false;
      }
      else if (bTimer1Active && timer1_ms <= 0) {
        //GPS.sendCommand(PMTK_API_SET_FIX_CTL_1HZ);
        //GPS.sendCommand(PMTK_SET_NMEA_UPDATE_1HZ);
        bTimer4Active = false;
        Serial.println("Switching to STATE_WAIT");
        setBlinkState ( BLINK_STATE_OFF );
        nAppState = STATE_WAIT;
        bTimer1Active = false;

        // set nav update rate to 1Hz
        myGNSS.setNavigationFrequency(1);
        
        stopLogFileFlushing();
        logFile.close();
        
      }
      
    }
    break;

  case STATE_LANDED_2:
    {
      
      if (nmea.isValid() && nmea.getSpeed() >= TEST_SPEED_THRESHOLD_KTS*1000) {
        nAppState = STATE_IN_FLIGHT;
        bTimer1Active = false;
      }
      else if (bTimer1Active && timer1_ms <= 0) {
        //GPS.sendCommand(PMTK_API_SET_FIX_CTL_1HZ);
        //GPS.sendCommand(PMTK_SET_NMEA_UPDATE_1HZ);
        bTimer4Active = false;
        setBlinkState ( BLINK_STATE_OFF );
        nAppState = STATE_WAIT;
        Serial.println("Switching to STATE_WAIT");
        bTimer1Active = false;
        bTimer5Active = false;

        stopLogFileFlushing();
        logFile.close();
      }
    }
    break;
  }
}

void updateFlightStateMachine() {

  /**
   * State machine appropriate for flight
   */
  switch (nAppState) {

  case STATE_WAIT:
    if (nHDot_fpm > OPS_HDOT_THRESHOLD_FPM) {

      Serial.println("Switching to STATE_IN_FLIGHT");
      
      // open log file
      generateLogname( logpath );
      logFile = SD.open( logpath, FILE_WRITE );

      logFile.println( NMEA_APP_STRING );

      // Activate altitude / battery sensor logging
      bTimer4Active = true;
      timer4_ms = TIMER4_INTERVAL_MS;

      // Activate periodic log file flushing
      startLogFileFlushing();

      // Activate "in flight" LED blinking
      setBlinkState ( BLINK_STATE_LOGGING );

      // Set "time 0" for log file.
      ulLogfileOriginMillis = millis();
      
      nAppState = STATE_IN_FLIGHT;
    }
    break;

  case STATE_IN_FLIGHT:
    {
      if (nHDot_fpm <= OPS_HDOT_JUMPING_FPM) {
        Serial.println("Switching to STATE_JUMPING");
        nAppState = STATE_JUMPING;

        // set nav update rate to 4Hz
        myGNSS.setMeasurementRate(250);
        myGNSS.setNavigationRate(1);

        myGNSS.disableNMEAMessage( UBX_NMEA_GSA, COM_PORT_I2C );
        myGNSS.disableNMEAMessage (UBX_NMEA_GSV, COM_PORT_I2C );
      }
    }
    break;

  case STATE_JUMPING:
    {
      if (labs(nHDot_fpm) <= OPS_HDOT_LAND_THRESHOLD_FPM) {
        Serial.println("Switching to STATE_LANDED_1");
        nAppState = STATE_LANDED_1;
        timer1_ms = TIMER1_INTERVAL_MS;
        bTimer1Active = true;
      }
    }
    break;

  case STATE_LANDED_1:
    {
      if (nHDot_fpm <= OPS_HDOT_JUMPING_FPM) {
        Serial.println("Switching to STATE_JUMPING");
        nAppState = STATE_JUMPING;
        bTimer1Active = false;
      }
      else if (labs(nHDot_fpm) >= OPS_HDOT_THRESHOLD_FPM) {
        Serial.println("Switching to STATE_IN_FLIGHT");
        nAppState = STATE_IN_FLIGHT;
        bTimer1Active = false;
      }
      else if (bTimer1Active && timer1_ms <= 0) {

        // Back to 0.5Hz update rate
        myGNSS.setMeasurementRate(2000);
        myGNSS.setNavigationRate(1);

        myGNSS.enableNMEAMessage( UBX_NMEA_GSA, COM_PORT_I2C );
        myGNSS.enableNMEAMessage (UBX_NMEA_GSV, COM_PORT_I2C );
        
        bTimer4Active = false;
        Serial.println("Switching to STATE_WAIT");
        setBlinkState ( BLINK_STATE_OFF );
        nAppState = STATE_WAIT;
        bTimer1Active = false;

        stopLogFileFlushing();
        logFile.close();
      }
    }
    break;
  }
}

/*
 * Start of USB Disk callbacks
 */

// Callback invoked when received READ10 command.
// Copy disk's data to buffer (up to bufsize) and
// return number of copied bytes (must be multiple of block size)
int32_t msc_read_cb (uint32_t lba, void* buffer, uint32_t bufsize)
{
  (void) bufsize;
  return SD.getCard().readBlock(lba, (uint8_t*) buffer) ? 512 : -1;
}

// Callback invoked when received WRITE10 command.
// Process data in buffer to disk's storage and 
// return number of written bytes (must be multiple of block size)
int32_t msc_write_cb (uint32_t lba, uint8_t* buffer, uint32_t bufsize)
{
  (void) bufsize;
  return SD.getCard().writeBlock(lba, buffer) ? 512 : -1;
}

// Callback invoked when WRITE10 command is completed (status received and accepted by host).
// used to flush any pending cache.
void msc_flush_cb (void)
{
  // nothing to do
}


/*
 * End of USB Disk callbacks
 */
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
void loop() {

  uint32_t curTime_ms = millis();

  uint32_t deltaTime_ms = curTime_ms - lastTime_ms;

  if ( deltaTime_ms > 0 ) {

    /*
     * Update active timer countdowns
     */
    if (bTimer1Active) {
      timer1_ms -= deltaTime_ms;
    }
  
    if (bTimer2Active) {
      timer2_ms -= deltaTime_ms;
    }
  
    if (bTimer3Active) {
      timer3_ms -= deltaTime_ms;
    }
  
    if (bTimer4Active) {
      timer4_ms -= deltaTime_ms;
    }

    if (bTimer5Active) {
      timer5_ms -= deltaTime_ms;
    }
    
    lastTime_ms = curTime_ms;

  }

  myGNSS.checkUblox();

#ifdef notdef
  while ( GPS.available() > 0 ) {
  
    char c = GPS.read();
  
    /*
     * Received a NMEA record terminator?  Process it.
     */
    if ( GPS.newNMEAreceived() ) {
  
      strcpy( lastNMEA, GPS.lastNMEA() );

      if (logFile) {
        logFile.print( lastNMEA );
        flushLog();
      }
  
      if ( printNMEA ) {
        Serial.print( lastNMEA );
      }
  
      /*
       * Parse this latest arriving NMEA record. This will update appropriate state
       * variables in the GPS object. Calling GPS.lastNMEA() also has the effect of clearing the
       * flag indicating a new record arrived.
       */
      if (!GPS.parse( lastNMEA )) {
        // message not useful to us, or (less likely) had invalid checksum
      }
  
    }

  }
#endif

  /*
   * Processing tasks below are outside of the
   * GPS NMEA processing loop.
   */

  if (OPS_MODE == OPS_GROUND_TEST) {
    updateTestStateMachine();
  }
  else {
    updateFlightStateMachine();
  }

  sampleAndLogAltitude();

  /*
   * RED LED Blink Logic
   * 
   * The RED LED will blink using different patterns to indicate
   * one of three states: Constant off, ON/OFF at 1.5Hz to indicates a low battery.
   * A 3-second blink is used to indicate flight mode.
   */
  if (bTimer3Active && timer3_ms <= 0) {
    
    redLEDState = (redLEDState == HIGH) ? LOW : HIGH;
    digitalWrite(RED_LED, redLEDState);

    if ( redLEDState == HIGH ) {
      timer3_ms = TIMER3_ON_INTERVAL_MS;
    }
    else {
      timer3_ms = bBatteryAlarm ? TIMER3_OFF_INTERVAL_1_MS : TIMER3_OFF_INTERVAL_2_MS;
    }
    
  }

  /*
   * Every 30 seconds, measure the battery state.
   * Blink red LED if low.
   */
  if (bTimer2Active && timer2_ms <= 0) {
    
    timer2_ms = TIMER2_INTERVAL_MS;
    
    measuredBattery_volts = analogRead( VBATPIN );
    measuredBattery_volts *= 2;    // we divided by 2, so multiply back
    measuredBattery_volts *= 3.3;  // Multiply by 3.3V, our reference voltage
    measuredBattery_volts /= 1024; // convert to voltage

    if ( measuredBattery_volts <= LOWBATT_THRESHOLD ) {
      bBatteryAlarm = true;
      setBlinkState ( BLINK_STATE_BATTERY );
    }
    else {
      if ( bBatteryAlarm ) {
        setBlinkState( (nAppState != STATE_WAIT) ? BLINK_STATE_LOGGING : BLINK_STATE_OFF );
      }
      bBatteryAlarm = false;
    }
  }

  /*
   * Log BME sensor information
   */
  if (bTimer4Active && timer4_ms <= 0) {
 
    //BMESample();
    IMU();

    timer4_ms = TIMER4_INTERVAL_MS;
  }

  /*
   * Yield - primarily as insurance the SD card driver gets control when
   *         required.
   */

  yield();
  
}

/*
void BMESample() {

  if (nAppState != STATE_WAIT) {
    
    if (! bme.performReading()) {
      Serial.println("Failed to perform BME888 reading :(");
      return;
    }

    if (logFile ) {
    
      logFile.print("$PENV,");
      logFile.print(millis());
      logFile.print(",");
      logFile.print(bme.temperature);
      logFile.print(",");
      logFile.print(bme.pressure / 100.0);
      logFile.print(",");
      logFile.print(bme.humidity);
      logFile.print(",");
      logFile.print(bme.readAltitude(SEALEVELPRESSURE_HPA));
      logFile.print(",");
      logFile.print(bme.gas_resistance / 1000.0);
      logFile.print(",");
      logFile.println(measuredBattery_volts);

    }
  }
}
*/

/*
void PressureSample() {

  if (nAppState != STATE_WAIT) {
    
    if (! bme.performReading()) {
      Serial.println("Failed to perform BME888 reading :(");
      return;
    }

    if (logFile ) {
    
      logFile.print("$PENV,");
      logFile.print(millis() - ulLogfileOriginMillis);
      logFile.print(",");
      logFile.print(bme.temperature);
      logFile.print(",");
      logFile.print(bme.pressure / 100.0);
      logFile.print(",");
      logFile.print(bme.humidity);
      logFile.print(",");
      logFile.print(bme.readAltitude(SEALEVELPRESSURE_HPA));
      logFile.print(",");
      logFile.print(bme.gas_resistance / 1000.0);
      logFile.print(",");
      logFile.println(measuredBattery_volts);

    }
  }
}
*/

void startLogFileFlushing()
{
  if (! bTimer5Active) {
    timer5_ms = TIMER5_INTERVAL_MS;
    bTimer5Active = true;
  }
}

void stopLogFileFlushing()
{
  if (bTimer5Active) {
    timer5_ms = 0;
    bTimer5Active = false;
  }

  if ( logFile ) {
    logFile.flush();
  }
}

void flushLog() {
    
  if (bTimer5Active && timer5_ms <= 0) {
    
    //Serial.println( "Log flushing" );

    timer5_ms = TIMER5_INTERVAL_MS;

    if ( logFile ) {
      logFile.flush();
    }
    
  }
}

void IMU() {

  if (imuPresent) {
    
    sensors_event_t a, g, temp;
    mpu.getEvent(&a, &g, &temp);

#ifdef notdef
    Serial.print(g.gyro.x); // rad per sec
    Serial.print(",");
    Serial.print(g.gyro.y);
    Serial.print(",");
    Serial.print(g.gyro.z);
    Serial.println();
#endif
  
    if (logFile) {
      logFile.print("$PIMU,");
      logFile.print(millis() - ulLogfileOriginMillis);
      
      logFile.print(",");
      logFile.print(a.acceleration.x);  // m/s^2
      logFile.print(",");
      logFile.print(a.acceleration.y);
      logFile.print(",");
      logFile.print(a.acceleration.z);
      
      logFile.print(",");
      logFile.print(g.gyro.x); // rad per sec
      logFile.print(",");
      logFile.print(g.gyro.y);
      logFile.print(",");
      logFile.print(g.gyro.z);
      logFile.println();
    }
  }
}

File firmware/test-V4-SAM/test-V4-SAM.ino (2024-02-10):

/* 

  Test peripheral interfaces that we'll use with the Tempo hardware

  This application is an amalgam of several open source Arduino projects.
  It was used to test several different processor board with the Peakick sensor array.

  Elements based on code by Kris Winer
  "01/14/2022 Copyright Tlera Corporation"
  "Library may be used freely and without limit with proper attribution."
  see https://github.com/kriswiner/ICM42688

*/

#include <Arduino.h>
#include <stdio.h>
#include <avr/dtostrf.h>

#include "Adafruit_ZeroTimer.h"
#include "ICM42688.h"
#include "bmp3.h"
#include <SparkFun_u-blox_GNSS_Arduino_Library.h>

SFE_UBLOX_GNSS myGNSS;

#define GPS_I2C_ADDR      0x42  // SAM-M10Q
#define ICM42688_ADDR     0x69

// "true" for extended Serial debugging messages
#define SerialDebug false

volatile bool alarmFlag = false;  // for RTC alarm interrupt

#if defined(ESP32)

#include <ESP32Time.h>
#include "ESP32TimerInterrupt.h"

// Sparkfun ESP32 Thing Plus C
#define RED_LED           13
#define GREEN_LED         12
#define CLKOUT            14        // ESP32 GPIO14 on the Sparkfun ESP32 Thing Plus C

// Unused in the current code, but I experimented with supplying the IMU clock from the ESP32
// using the ESP32 ledc API.
#define CPU_SUPPLIES_IMU_CLKIN  false
#define LEDC_CLKIN_CHANNEL    7     // channel (chosen randomly)
#define LEDC_CLKIN_RESOLUTION 8     // 8-BIT COUNTER (0..255)
#define LEDC_CLKIN_BASE_FREQ 32768  // Hz
#define LEDC_DUTY_CYCLE      128    // 50% duty cycle on a 8-bit counter

// ESP32 Thing Plus C/peackick-specific interrupt line connections
#define ICM42688_intPin1 32  // INT/INT1
#define ICM42688_intPin2 14  // INT2/CLKIN
#define MMC5983MA_intPin 15
#define BMP390_intPin    33
#endif

#if defined(STM32F4xx)
// Sparkfun STM-32 (DEV-17712)
#define RED_LED           13
#define GREEN_LED         12
#define CLKOUT            5        

#define CPU_SUPPLIES_IMU_CLKIN  false

// ESP32 Thing Plus C/peackick-specific interrupt line connections
#define ICM42688_intPin1 6  // INT/INT1
#define ICM42688_intPin2 5  // INT2/CLKIN
#define MMC5983MA_intPin 9
#define BMP390_intPin    10

#define IRAM_ATTR

#include <STM32RTC.h>

static STM32RTC::Hour_Format hourFormat = STM32RTC::HOUR_24;
static STM32RTC::AM_PM period = STM32RTC::AM;

STM32RTC& rtc = STM32RTC::getInstance();

void rtc_SecondsCB(void *data)
{
  UNUSED(data);
  alarmFlag = true;
}

#endif

// A small hack to automatically identify the Sparkfun SAMD21 board
//#if defined(_SAMD51J20A_)
#define DROPKICK_V4_SAM
//#endif

#if defined(DROPKICK_V4_SAM)

/**
 * DROPKICK V4 SAM SAMD21G18A 
 * 
 * BMP390    INT       D6
 * ICM42688  INT/INT1  D11
 * ICM42688  INT2      D12
 * 
 */
#define RED_LED           13
#define GREEN_LED         12
#define CLKOUT            5         // as a D51 output line     

#define CPU_SUPPLIES_IMU_CLKIN  false

// SAMD51 Thing Plus C/peackick-specific interrupt line connections
#define ICM42688_intPin1 digitalPinToInterrupt(11)   // INT/INT1
#define ICM42688_intPin2 digitalPinToInterrupt(12)   // INT2/CLKIN as an interrupt line
#define BMP390_intPin    digitalPinToInterrupt(6)

#define IRAM_ATTR

// This example can have just about any frequency for the callback
// automatically calculated!
float freq = 1000.0; // 1 KHz

// timer tester
Adafruit_ZeroTimer zerotimer = Adafruit_ZeroTimer(3);

void TC3_Handler() {
  Adafruit_ZeroTimer::timerHandler(3);
}

void TimerCallback0(void)
{
  alarmFlag = true;
}

#endif

#define bmp3_check_rslt(func, r)                     \
    if (r != BMP3_OK) {                              \
        Serial.println("Error returned from " func); \
    }

// global constants for 9 DoF fusion and AHRS
float pi = 3.141592653589793238462643383279502884f;
float GyroMeasError =
    pi * (40.0f /
          180.0f);  // gyroscope measurement error in rads/s (start at 40 deg/s)
float GyroMeasDrift =
    pi *
    (0.0f /
     180.0f);  // gyroscope measurement drift in rad/s/s (start at 0.0 deg/s/s)
float beta = sqrtf(3.0f / 4.0f) * GyroMeasError;  // compute beta
float zeta =
    sqrtf(3.0f / 4.0f) *
    GyroMeasDrift;  // compute zeta, the other free parameter in the Madgwick
                    // scheme usually set to a small or zero value
float pitch, yaw, roll;  // absolute orientation
float a12, a22, a31, a32,
    a33;  // rotation matrix coefficients for Euler angles and gravity
          // components
float deltat = 0.0f,
      sum = 0.0f;  // integration interval for both filter schemes
uint32_t lastUpdate = 0,
         firstUpdate = 0;  // used to calculate integration interval
uint32_t Now = 0;          // used to calculate integration interval
float lin_ax, lin_ay,
    lin_az;  // linear acceleration (acceleration with gravity component
             // subtracted)
float q[4] = {1.0f, 0.0f, 0.0f, 0.0f};  // vector to hold quaternion
float eInt[3] = {0.0f, 0.0f,
                 0.0f};  // vector to hold integral error for Mahony method

extern void IRAM_ATTR MadgwickQuaternionUpdate(float ax, float ay, float az,
                                               float gx, float gy, float gz,
                                               float mx, float my, float mz);


/* Specify sensor parameters (sample rate is twice the bandwidth)
 * choices are:
      AFS_2G, AFS_4G, AFS_8G, AFS_16G
      GFS_15_625DPS, GFS_31_25DPS, GFS_62_5DPS, GFS_125DPS, GFS_250DPS,
 GFS_500DPS, GFS_1000DPS, GFS_2000DPS AODR_1_5625Hz, AODR_3_125Hz, AODR_6_25Hz,
 AODR_50AODR_12_5Hz, AODR_25Hz, AODR_50Hz, AODR_100Hz, AODR_200Hz, AODR_500Hz,
      AODR_1kHz, AODR_2kHz, AODR_4kHz, AODR_8kHz, AODR_16kHz, AODR_32kHz
      GODR_12_5Hz, GODR_25Hz, GODR_50Hz, GODR_100Hz, GODR_200Hz, GODR_500Hz,
 GODR_1kHz, GODR_2kHz, GODR_4kHz, GODR_8kHz, GODR_16kHz, GODR_32kHz
*/
uint8_t Ascale = AFS_4G, Gscale = GFS_250DPS, AODR = AODR_200Hz,
        GODR = GODR_200Hz, aMode = aMode_LN, gMode = gMode_LN;

// must be set to match accel/gyro samples
float fSampleInterval_sec = 1 / 200.0f;

float aRes, gRes;  // scale resolutions per LSB for the accel and gyro sensor2
float accelBias[3] = {0.0f, 0.0f, 0.0f},
      gyroBias[3] = {0.0f, 0.0f, 0.0f};  // offset biases for the accel and gyro
int16_t accelDiff[3] = {0, 0, 0},
        gyroDiff[3] = {0, 0, 0};  // difference betwee ST and normal values
float STratio[7] = {
    0.0f, 0.0f, 0.0f, 0.0f,
    0.0f, 0.0f, 0.0f};    // self-test results for the accel and gyro
int16_t ICM42688Data[7];  // Stores the 16-bit signed sensor output
float imuTemp_C;  // Stores the real internal gyro temperature in degrees
                     // Celsius
float ax, ay, az, gx, gy,
    gz;  // variables to hold latest accel/gyro data values

volatile uint16_t imuISRCount = 0;

ICM42688 imu(&Wire);


#define SEALEVELPRESSURE_HPA (1013.25)

volatile bool pressureSampleAvailable = false;

void IRAM_ATTR BMPSampleReadyHandler() { pressureSampleAvailable = true; }
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

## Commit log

2022-01-22 inital directory structure
    [Lower.step, Upper.step, dropkick.f3z]
2022-01-24 Add 3d PCB model and updated main image
2022-01-24 Add PDF of schematic
2022-01-26 Add u-block CAM-M8Q symbol and footprint
2022-01-26 Correct CAM-M8C footprint
2022-01-28 V3 board
    [Lower.step, Upper.step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]
2022-01-28 Add u-blox CAM STEP model
    [CAM.STEP, dropkick.kicad_pcb]
2022-01-29 Alternate REG IC
    [dropkick.kicad_sch]
2022-01-29 IC substitutions
    [dropkick.kicad_sch]
2022-01-30 Reorganize footprint libraries
    [dropkick.kicad_pcb, dropkick.kicad_sch]
2022-01-30 Add enclosure printing notes
2022-02-21 Add BOM, minor footprint fixes
    [dropkick-bom.xlsx, dropkick.kicad_pcb, dropkick.kicad_sch]
2022-03-01 Tweak BOM, add MFR part numbers
    [dropkick.kicad_sch]
2022-03-03 update schematic PDF
2022-03-08 V4 board candidate
    [dropkick.kicad_pcb, dropkick.kicad_sch]
2022-05-01 Add PCB/reflow notes
2022-05-02 add PCB definitions for both SAM and CAM variants
    [10103594.stp, 20021521-00010XXLFc.stp, CAM.STEP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]
2022-05-03 Add explanation of the two PCB folders
2022-05-03 add gerber files
    [dropkick-B_Cu.gbr, dropkick-B_Mask.gbr, dropkick-B_Paste.gbr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]
2022-07-23 GNSS sampling now 2Hz during jump
2022-08-01 updated enclosure and enhanced SAM-M8 footprint
2022-08-01 add diagram for IMU axes
2022-08-04 add strapdown flow image
2022-08-05 save experiments
    [FF214-IMU.csv]
2022-08-13 Add images
    [switch.step]
2022-08-19 latest test baseline. focus on strapdown phase.
2023-02-18 use internal antenna only
    [dropkick-B_Cu.gbr, dropkick-B_Mask.gbr, dropkick-B_Paste.gbr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]
2023-08-09 v3 SAM PCB
    [dropkick-B_Cu.gbr, dropkick-B_Mask.gbr, dropkick-B_Paste.gbr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]
2023-08-12 V4 SAM PCB
    [ICM-42688-P.step, LGA10_BMP390_BOS.step, STP_450405020524 (rev1).stp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]
2023-08-15 V4 SAM
    [dropkick.kicad_pcb, dropkick.kicad_sch]
2023-09-13 V4 SAM PCB notes
2023-09-22 Updated enclosure for V4 PCB
    Includes USB-C clearance
    [Lower.step, Upper.step]
2023-09-27 Update paste margins on ICM42688; minor pcb trace
    [dropkick.kicad_pcb]
2023-10-01 V5-CAM PCB
    [dropkick.kicad_pcb, dropkick.kicad_sch]
2023-10-01 V5-CAM add INT line to MPU6050
    [dropkick.kicad_pcb, dropkick.kicad_sch]
2023-10-02 Clean up AD0 address line for MPU6050
    [dropkick.kicad_pcb, dropkick.kicad_sch]
2023-10-02 Fix MPU6050 footprint; gerber plot
    [dropkick-B_Cu.gbr, dropkick-B_Mask.gbr, dropkick-B_Paste.gbr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]
2023-10-02 Improve LED wiring consistency; update gerber
    [dropkick-B_Cu.gbr, dropkick-B_Mask.gbr, dropkick-B_Paste.gbr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]
2023-10-02 Add mfr info
    [dropkick.kicad_pcb, dropkick.kicad_sch]
2023-10-02 Add VLOGIC bypass cap to 6050; update gerbers
    [dropkick-B_Cu.gbr, dropkick-B_Mask.gbr, dropkick-B_Paste.gbr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]
2023-10-03 Upgrade to KiCad 7
    [dropkick-B_Cu.gbr, dropkick-B_Mask.gbr, dropkick-B_Paste.gbr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]
2023-10-03 Switch to 2.0mm pads and added SWDIO/SWCLK pads to flash w/o header
    [dropkick-B_Cu.gbr, dropkick-B_Mask.gbr, dropkick-B_Paste.gbr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]
2023-10-04 Update new enclosure to prevent closing hang-ups
    [Lower.step, Upper.step]
2023-10-04 Added extra CAP per DPS310 datasheet
    [dropkick-B_Cu.gbr, dropkick-B_Mask.gbr, dropkick-B_Paste.gbr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]
2023-10-04 Add boxes to schematic; clean up PCB placement; use PCBWay gerber settings
    [dropkick-B_Cu.gbr, dropkick-B_Mask.gbr, dropkick-B_Paste.gbr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]
2023-10-06 Update switch
    [dropkick.kicad_sch]
2024-11-14 Add Temp frames diagram

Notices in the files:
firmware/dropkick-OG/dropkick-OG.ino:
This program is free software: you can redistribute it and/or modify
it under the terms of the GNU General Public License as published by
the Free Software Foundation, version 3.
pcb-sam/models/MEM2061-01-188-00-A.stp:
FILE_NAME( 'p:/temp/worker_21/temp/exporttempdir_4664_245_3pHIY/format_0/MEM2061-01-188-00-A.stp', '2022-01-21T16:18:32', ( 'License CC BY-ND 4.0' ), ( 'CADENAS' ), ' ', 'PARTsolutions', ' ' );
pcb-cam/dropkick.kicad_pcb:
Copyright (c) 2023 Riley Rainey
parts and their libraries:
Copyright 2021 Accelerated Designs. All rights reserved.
